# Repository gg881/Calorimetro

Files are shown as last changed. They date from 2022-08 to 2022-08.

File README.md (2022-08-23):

# Calorímetro

Neste github estão todos os arquivos do projeto, entre eles arquivos de construção mecânica, arquivo de software, firmware, executável e alguns ensaios.
Existem 3 vídeos explicando melhor sobre o projeto.

<br>

**Vídeo 1:**  Aborda sobre os detalhes da construção do projeto

Video 1 (https://www.youtube.com/watch?v=RRTPrstH1NE)

<br>

**Vídeo 2:**  Software, seu uso e procedimento de ensaio

Video 2 (https://www.youtube.com/watch?v=yg-kUi77DBA)

<br>

**Video3:** Procedimento de análise e resultados

Video 2 (https://www.youtube.com/watch?v=zke7yPpmnRY)

<br>
<br>

Contato:
gafaria@gmail.com ou gabriel.costa.faria@alumni.usp.br

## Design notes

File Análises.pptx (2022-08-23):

## Análise dos dados

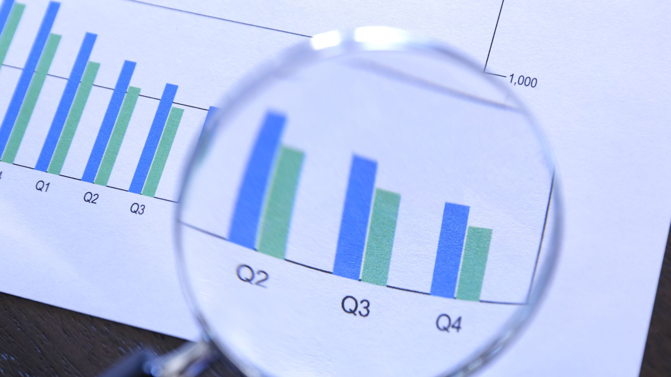
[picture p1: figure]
Lupa mostrando declínio de desempenho

## Tensão do ensaio

- Variando a tensão do ensaio, varia a potência máxima aplicada na amostra

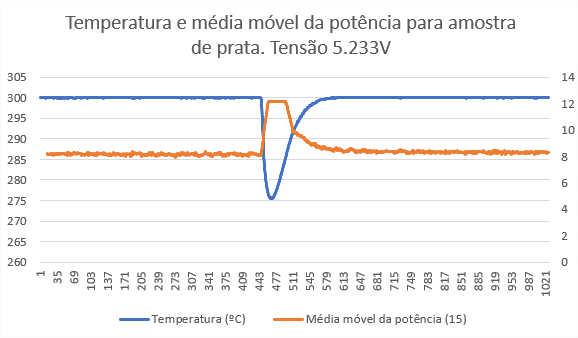
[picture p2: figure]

Pico de 12W, sem overshoot

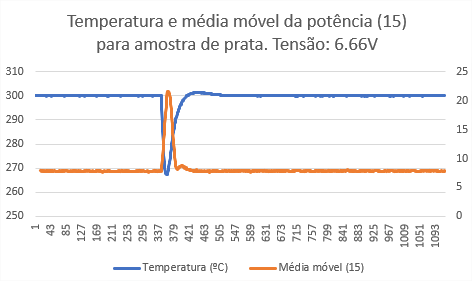
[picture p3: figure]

Pico de 21W. Teve overshoot!

## Como regular tensão

- Abrir a tampa frontal e ajustar no parafuso do trimpot rotacionando-o (o da esquerda). O trimpot da direita é a corrente limite.
- Pode deixar a saída manual em 1, verificando a máxima potência do ensaio.

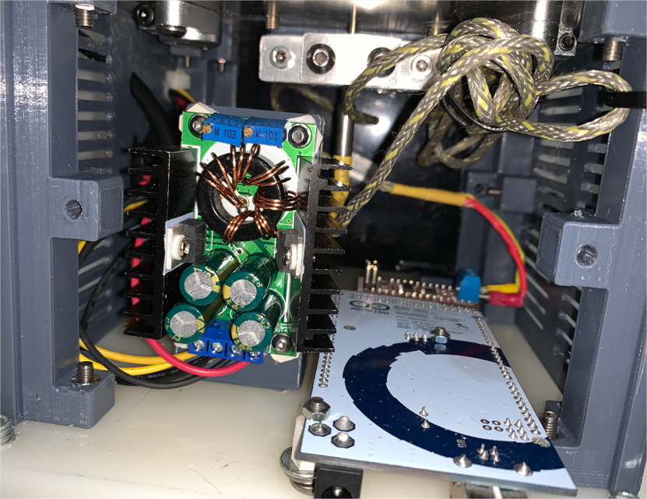
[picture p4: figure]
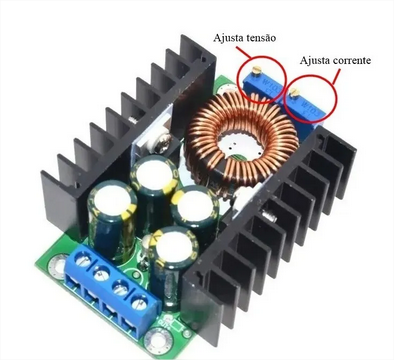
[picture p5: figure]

## Fim do ensaio quando não tem overshoot

- Considerado o momento que a temperatura atinge o patamar

## Fim do ensaio quando teve overshoot

- Considerado o momento que a temperatura retorna do overshoot (terminou o ciclo)

## Potências de estabilização com e sem a amostra

- São diferentes na maioria das vezes!
- Potência antes: 8.112W
- Potência depois: 8.270W
Mesmo pequena, afeta muito o resultado final
Em alguns casos chega a 0.3W a diferença

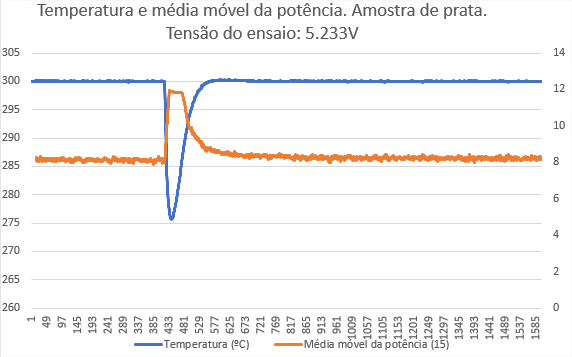
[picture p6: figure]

## Potências de estabilização com e sem a amostra

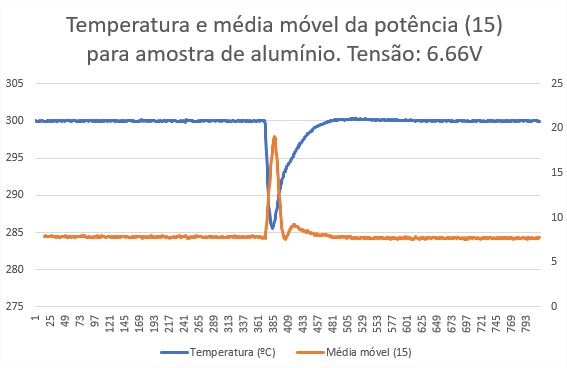
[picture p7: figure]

- Potência antes: 7,844W
- Potência depois: 7,707W

## Procedimento do ensaio

- Definir a temperatura do ensaio e valor do PID
- Esperar o aquecimento e estabilização da temperatura
- Começar a captura dos dados e capturar dados antes da amostra
- Colocar amostra e capturar dados depois da temperatura retornar
- Finalizar a captura de dados
- Análise dos dados no Excel

## Procedimento do cálculo dos valores (Excel)

- Nos ensaios foi considerada a 50% da média antes e 50% depois.
- O tempo inicial foi considerado o tempo que começa a cair a temperatura.
- O tempo final foi considerado de acordo com a existência de overshoot. Com ele: quando retorna do overshoot pela primeira vez. Sem ele: quando retorna para a temperatura definida pela primeira vez após o ensaio.
- É calculado o tempo do ensaio e a potência média durante o ensaio e potência média antes e depois.
- Fórmula usada: = (potência média do ensaio - (0,5*potência média antes do ensaio + 0,5* potência média depois do ensaio) ) ) * tempo do ensaio

## planilha

## Zinco

- P: 5.68 I: 104.06 D: 26.00 Tensão:6.631 V
- Temperatura ambiente: 21.0ºC
- Massa: 3,246 g

## Zinco amostra 1

Teve overshoot. Energia absorvida: 376,5 J

## Zinco amostra 2

Teve overshoot. Energia absorvida: 377,6 J

## Zinco amostra 3

Teve overshoot. Energia absorvida: 394,2 J

Média dos ensaios: 382,9 J

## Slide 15

Média dos ensaios: 382,9 J
Cálculo do valor esperado teórico:
Temperatura inicial média: 20,5ºC
No intervalo:

=1785,95 cal/mol = 7472,4 J/mol = 114,29 J/g * 3,246g = 370,99 J
Valor esperado: 371,0 J
Erro relativo: (382,9-371)/371 = 0,032 = 3.2% de erro

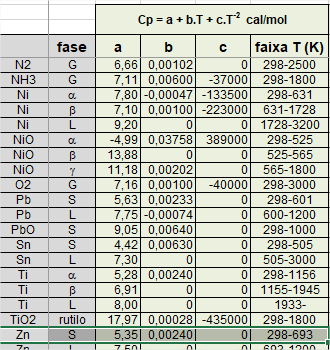
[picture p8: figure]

## Outra fonte de dados

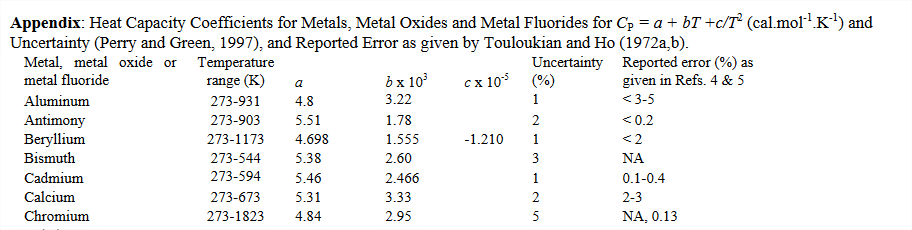
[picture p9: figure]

= 114,82 J/g = 372,7 J
Erro relativo: (382,9-372,7)/372,7 = 0,027 = 2,7% de erro

## E se a tensão for menor?

- Amostras com 5.236V
- P: 12.00 I: 119.90 D: 29.90

## Amostra 1b

Energia absorvida: 347,2 J

Ensaio ruim:
Não estava estabilizada a potência

## Amostra 2b

Energia absorvida: 364,5 J

## Amostra 2c

Ensaio ruim:
Não estava estabilizada a potência

Energia absorvida: 344,5 J

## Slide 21

- Média das amostras: 352,1 J
- Fonte 1: (352,1-371,0)/371,0 = -0,051 = – 5,1 % erro
- Fonte 2: (352,1-372,7)/372,7 =-0,055 = – 5,5% erro
- Ensaio ruim, patamar não estável

## E se a tensão for maior?

P: 3.00 I: 118.00 D: 29.50 Tensão:9.482 V Temperatura ambiente: 23.61ºC

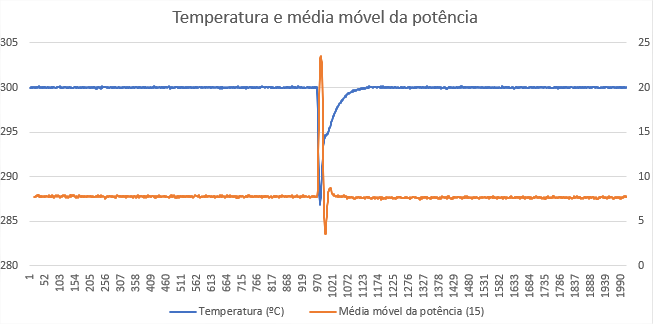
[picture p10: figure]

Amostra 1: 372,8 J

## E se a tensão for maior?

P: 3.00 I: 118.00 D: 29.50 Tensão:9.482 V Temperatura ambiente: 23.61ºC

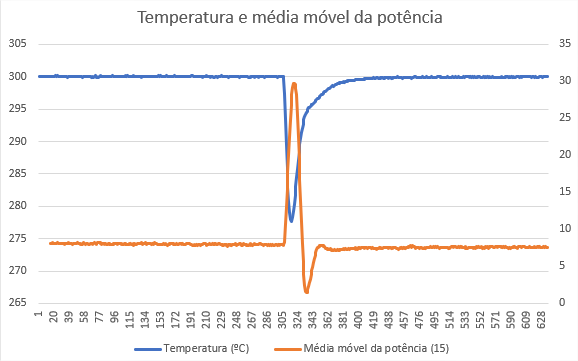
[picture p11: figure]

Amostra 2: 388,1 J

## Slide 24

- Média das amostras: 380,45 J
- Fonte 1: (380,45-371,0)/371,0 = 0,025 = 2,5 % erro
- Fonte 2: (380,4-372,7)/372,7 = 0,021 = 2,1% erro

## Amostra de prata

P: 5.68 I: 104.06 D: 26.00
Tensão:6.636 V
Temperatura ambiente: 21.73ºC
Massa: 8,852g

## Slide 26

Amostra 1: 666,7J
Amostra 2: 610,5 j
Amostra 3: 699,7 J
Média de 648,9 J

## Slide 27

1740,8 cal/mol * 4,184 J/cal / 107,868 g/mol = 67,52 J/g * 8,852g = 597,7 J

Erro relativo = (648,9-597,7)/597,7 = 0,085 = 8,5% de erro

## Amostra de prata – tensão menor

- P: 12.50 I: 100.00 D: 23.80
- Tensão:5.233 V

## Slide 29

- Amostra 1: 614,1 J
- Amostra 2: 552,2 J
- Amostra 3: 580,7 J
- Média: 582,3 J
- Erro relativo: (582,3-597,7)/597,7 = -0,0257 = -2,6% de erro

## Amostra de chumbo (chumbada de pesca)

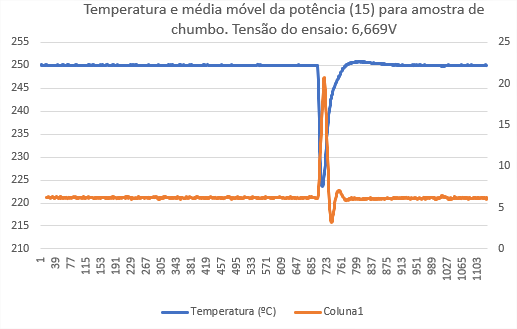
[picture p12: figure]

Amostra 1: Teve overshoot. Energia absorvida: 375,8 J

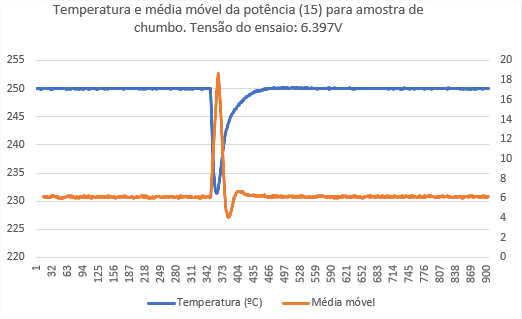
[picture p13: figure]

Amostra 2: Sem overshoot. Energia absorvida: 361,3 J

- Somente 2 ensaios (um em cada tensão)
- Média: 368,5 J

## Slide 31

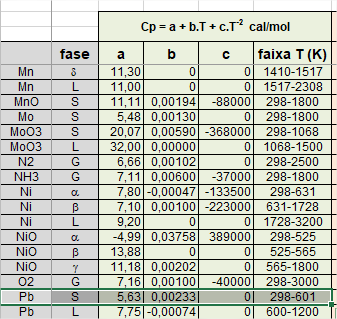
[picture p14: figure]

1488,28 cal/mol * 4,184 J/cal / 207,2 g/mol = 30,05 J/g
30,05 J/g * 12,448g = 374,1 J
Valor obtido experimentalmente: 368,5 J
Erro relativo: (368,5-374,1)/374,1 = -0,0149 = -1,5% de erro

## Amostra de Alumínio

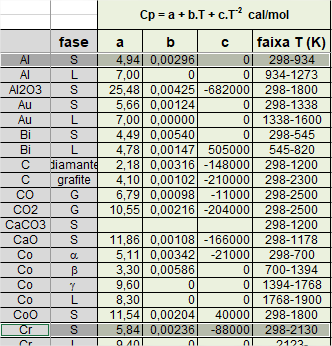
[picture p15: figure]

- Liga 5052 (~ 96,7% de Al)
- Considerado como somente alumínio
- Ensaio em 300ºC

1736,26cal/mol * 4,184 J/cal / 26,98 g/mol = 269,25 J/g

Para a amostra:
Valor esperado: 269,2 J/g*1,676g = 451,3

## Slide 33

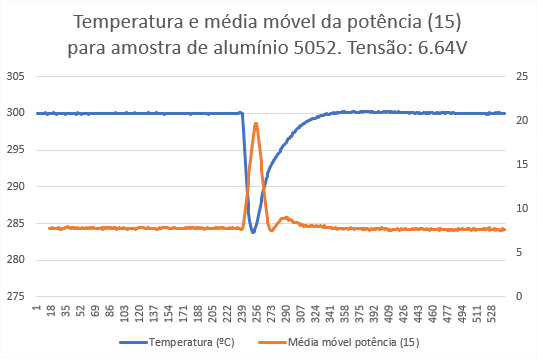
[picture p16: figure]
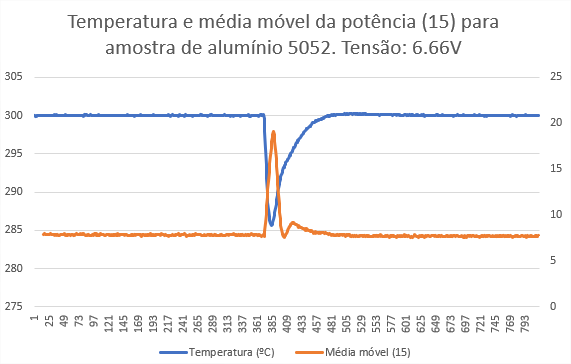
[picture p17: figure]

Teve overshoot.
Amostra 1: 437,3 J
Amostra 2: 419,5 J
Amostra 3: 445,3 J
Média de 434,0 J
Erro relativo: (434,0-451,3)/451,3 = -0,038 = -3,8% de erro

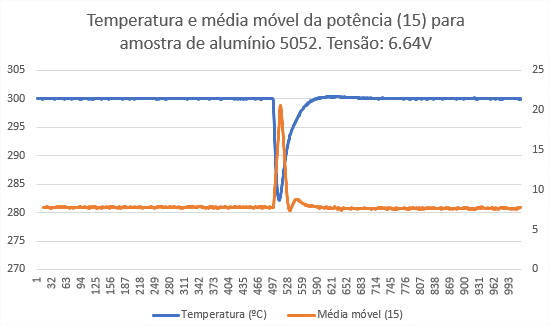
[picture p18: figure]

## Resumo

Amostra | Overshoot | Valor esperado | Valor obtido | Erro relativo
Zinco (6,631V) | sim | 371,0 J | 382,9 J | +3,2 %
Zinco (9,482V) | sim | 371,0 J | 380,45 J | +2,5 %
Prata 99% (6,67V) | sim | 597,7 J | 648,9 J | +8,5 %
Prata 99% (5,23V) | não | 597,7 J | 582,3 J | -2,6 %
Chumbo (chumbada) | ambos | 374,1 J | 368,5 J | -1,5%
Alumínio 5052 | sim | 451,3 J | 434,0 J | -3,8 %

## Sugestão de melhoria

- Realizar mais testes com e sem overshoot e protocolo de medição
- Ensaios para determinar tensão correta do ensaio
- Implementar medida automática no software
- Verificar precisão do termopar
- Verificar precisão do sensor de corrente
- Altura correta do termopar? Gradiente de temperatura no calorímetro?
- Tamanho ideal de amostra?

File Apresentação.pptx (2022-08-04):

## Calorímetro

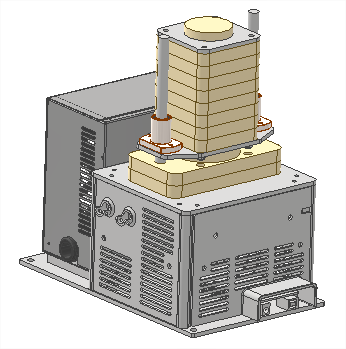
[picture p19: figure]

Documentação em:
www.github.com/gg881/Calorimetro

## Mede a quantidade de energia absorvida pela amostra até temperatura de teste

## Documentação em: www.github.com/gg881/Calorimetro

## Construção mecânica

- Modelado no Autodesk Inventor
- Construído com placas de fibra cerâmica, chapa de alumínio, nylon e partes impressas em PETG

## Eletrônica

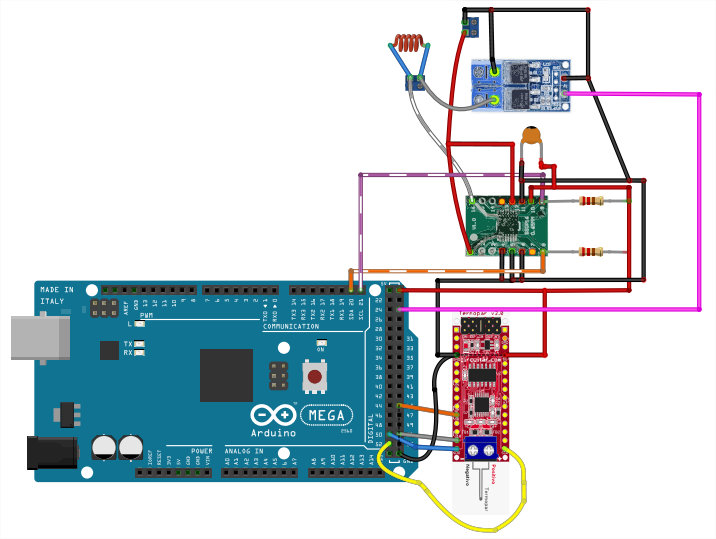
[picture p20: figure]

- Sensor de corrente e tensão (INA260)
- Sensor de temperatura (MAX31856)
- Arduino Mega 2560
- Mosfet para controle de potência
- Fonte 12v e regulador de tensão

## Medida da temperatura

- Módulo termopar da circuitar
- Baseado no CI MAX31856
- Linearização automática
- Suporta 8 tipos de termopares (K é o usado)
- Compensação junta fria
- Resolução de temperatura de 0.0078125°C (com termopar perfeito)

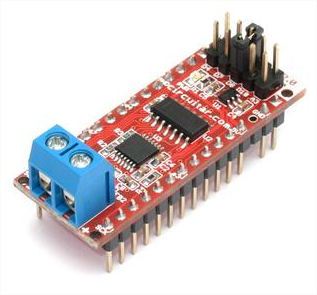
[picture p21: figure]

## Como é medida a corrente?

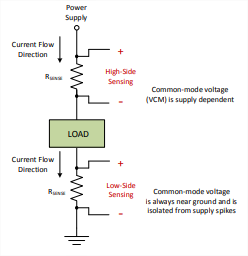
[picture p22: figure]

- Resistor shunt
- queda de tensão no resistor é proporcional à corrente
- Deve ser preciso, de baixo valor e termicamente estável

- https://www.ti.com/lit/an/sboa169b/sboa169b.pdf?ts=1653135314645

## Sensor de corrente – INA260

- Já vem com shunt interno (2mOhm) – 0,1%
- Resolução 1,25mA e 1,25mV
- -15A até 15A
- Até 16,488mS por leitura

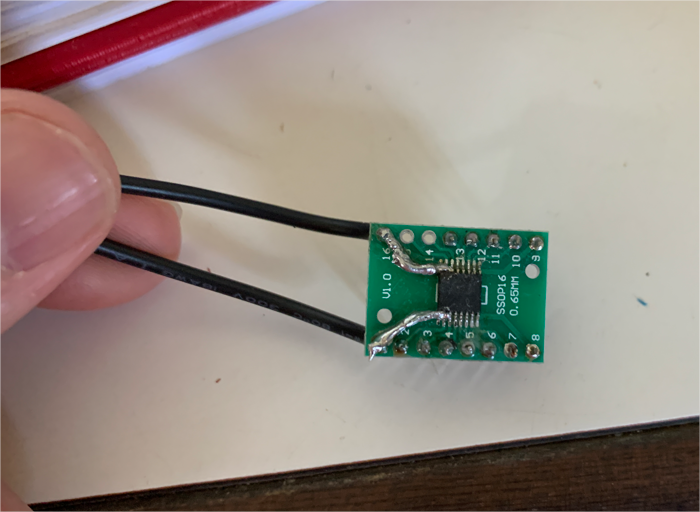
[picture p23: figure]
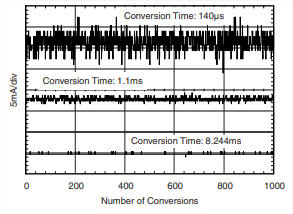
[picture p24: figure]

## Como é controlada a potência?

- Mosfet N
- Modulação PWM com período de 125 leituras do sensor (~2s)


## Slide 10


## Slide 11


## Firmware

- Lê os sensores
- Calcula a saída de carga a cada 125 leituras (algoritmo PID)
- Controla a saída
- Lê comandos do computador
- Formata e envia dados para o computador


## Algoritmo Proporcional Integrativo Derivativo (PID)

- Modula a potência de saída para que a temperatura seja constante


## PID

- Para cada sistema tem que ser calibrados os valores de P, I e D
- Não é trivial o ajuste sem um método.
- Centenas de métodos e variações
- O mais tradicional é o de Ziegler-Nichols

## Ziegler-Nichols


https://blog.opticontrols.com/archives/477

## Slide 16


## Ziegler-Nichols (frequência)


- No modo manual, colocar valores até começar a oscilar.

https://eng.libretexts.org/Bookshelves/Industrial_and_Systems_Engineering/Book%3A_Chemical_Process_Dynamics_and_Controls_(Woolf)/09%3A_Proportional-Integral-Derivati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

## Método de Astrom–Hagglund

- Método para calibração rápida
- Colocar em “bang-bang” e medir frequência e amplitude


Livro: Autotuning of PID Controllers Relay Feedback Approach - Cheng-Ching Yu - Springer


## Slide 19


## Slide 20


https://www.ni.com/pt-br/innovations/white-papers/06/pid-theory-explained.html

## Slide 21


https://www.pid-tuner.com/pid-control/

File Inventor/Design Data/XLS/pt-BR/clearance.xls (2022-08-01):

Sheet: Ansi Unified Screw Threads
I | Sort Order -1
Fastener Type | Size | Shaft Diameters |  |  | Head Dimensions
 |  | Close | Normal | Loose | Diameter | Depth/Angle | Head Type
Flat Head Machine Screw (82) | #0 | 0.0635 | 0.07 | 0.073 | 0.119 | 82 | 2
Flat Head Machine Screw (82) | #1 | 0.076 | 0.081 | 0.089 | 0.146 | 82 | 2
Flat Head Machine Screw (82) | #2 | 0.089 | 0.096 | 0.1065 | 0.172 | 82 | 2
Flat Head Machine Screw (82) | #3 | 0.104 | 0.11 | 0.12 | 0.199 | 82 | 2
Flat Head Machine Screw (82) | #4 | 0.116 | 0.1285 | 0.136 | 0.225 | 82 | 2
Flat Head Machine Screw (82) | #5 | 0.1285 | 0.136 | 0.154 | 0.252 | 82 | 2
Flat Head Machine Screw (82) | #6 | 0.144 | 0.1495 | 0.1695 | 0.279 | 82 | 2
Flat Head Machine Screw (82) | #8 | 0.1695 | 0.177 | 0.1935 | 0.332 | 82 | 2
Flat Head Machine Screw (82) | #10 | 0.196 | 0.201 | 0.221 | 0.385 | 82 | 2
Flat Head Machine Screw (82) | #12 | 0.221 | 0.228 | 0.246 | 0.438 | 82 | 2
Flat Head Machine Screw (82) | 1/4 | 0.257 | 0.266 | 0.2812 | 0.507 | 82 | 2
Flat Head Machine Screw (82) | 5/16 | 0.323 | 0.332 | 0.3437 | 0.635 | 82 | 2
Flat Head Machine Screw (82) | 3/8 | 0.386 | 0.397 | 0.4062 | 0.762 | 82 | 2
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

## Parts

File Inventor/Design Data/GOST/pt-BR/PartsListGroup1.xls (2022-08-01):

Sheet: Лист 1
Инв. № подл |  |  |  | Подп. и дата | Взам. инв. № | Инв. № дубл. |  |  | Подп. и дата
Формат | Зона | Поз. | Обозначение |  |  |  | Наименование |  |  |  |  |  | Кол. на исполнение
 |  |  |  |  |  |  |  |  |  |  |  | Лит.
 |  |  |  |  |  |  |  |  |  |  |  | Код
 |  |  |  |  |  |  |  | Изм. | Лист | № докум | Подпись |  | Дата
 |  |  |  |  |  |  |  | Разраб.
 |  |  |  |  |  |  |  | Пров.
 |  |  |  |  |  |  |  | Н.контр
 |  |  |  |  |  |  |  | Утв.
 |  |  |  |  |  |  |  |  |  |  |  |  |  | Копировал

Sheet: Лист 2
Инв. № подл |  |  |  | Подп. и дата | Взам. инв. № | Инв. № дубл. |  |  | Подп. и дата
Формат | Зона | Поз. | Обозначение |  |  |  | Наименование |  |  |  |  | Кол. на исполнение
 |  |  |  |  |  |  |  | Изм. | Лист | № докум. | Подп. | Дата
 |  |  |  |  |  |  |  |  |  |  |  |  | Копировал
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

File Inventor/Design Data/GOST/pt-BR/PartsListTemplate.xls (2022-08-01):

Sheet: Лист 1
 | Формат | Зона |  | Поз. |  | Обозначение |  |  |  | Наименование |  |  |  | Кол. | Приме-чание
Подп. и дата
Инв. № дубл.
Взам. инв. №
Подп. и дата
 | Изм. |  | Лист |  | № докум |  | Подпись | Дата
Инв. № подл | Разраб. |  |  |  |  |  |  |  |  |  | Литера |  | Лист |  |  | Листов
 | Пров.
 | Н.контр
 | Утв.
 |  |  |  |  |  |  |  |  | Копировал |  |  | Формат А4

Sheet: Лист 2
 | Формат | Зона |  | Поз. |  | Обозначение |  |  |  | Наименование |  | Кол. | Приме-чание
Подп. и дата
Инв. № дубл.
Взам. инв. №
Подп. и дата
Инв. № подл
 | Изм. |  | Лист |  | № докум. |  | Подп. |  | Дата
 |  |  |  |  |  |  |  | Копировал |  |  | Формат А4
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

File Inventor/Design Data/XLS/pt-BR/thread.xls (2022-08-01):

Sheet: Inch Tapping Threads
I Q X | Inch Tapping Threads |  | Sort Order - 5 |  | External |  |  |  |  |  |  | Internal
 |  |  |  |  |  | Major Dia |  | Pitch Dia |  | Minor Dia |  |  | Minor Dia |  | Pitch Dia |  | Major Dia |  | Tap Drill
Size | Size Suffix | Thread Designation | Custom Thread Designation | TPI | Class | Max | Min | Max | Min | Max | Min | Class | Min | Max | Min | Max | Min | Max | Basic
0.0600 |  | 0-48 | 0-48 | 48 | 2B | 0.0600 | 0.0540 | 0.0480 | 0.0435 | 0.0360 | 0.0330
0.0730 |  | 1-42 | 1-42 | 42 | 2B | 0.0750 | 0.0690 | 0.0620 | 0.0575 | 0.0490 | 0.0460
0.0860 |  | 2-32 | 2-32 | 32 | 2B | 0.0880 | 0.0820 | 0.0760 | 0.0710 | 0.0640 | 0.0600
0.0990 |  | 3-28 | 3-28 | 28 | 2B | 0.1010 | 0.0950 | 0.0880 | 0.0830 | 0.0750 | 0.0710
0.1120 |  | 4-24 | 4-24 | 24 | 2B | 0.1140 | 0.1080 | 0.1000 | 0.0950 | 0.0860 | 0.0820
0.1250 |  | 5-20 | 5-20 | 20 | 2B | 0.1300 | 0.1230 | 0.1120 | 0.1065 | 0.0940 | 0.0900
0.1380 |  | 6-20 | 6-20 | 20 | 2B | 0.1390 | 0.1320 | 0.1215 | 0.1155 | 0.1040 | 0.0990
0.1510 |  | 7-19 | 7-19 | 19 | 2B | 0.1540 | 0.1470 | 0.1345 | 0.1280 | 0.1150 | 0.1090
0.1640 |  | 8-18 | 8-18 | 18 | 2B | 0.1660 | 0.1590 | 0.1440 | 0.1375 | 0.1220 | 0.1160
0.1900 |  | 10-16 | 10-16 | 16 | 2B | 0.1890 | 0.1820 | 0.1650 | 0.1585 | 0.1410 | 0.1350
0.2160 |  | 12-14 | 12-14 | 14 | 2B | 0.2150 | 0.2080 | 0.1895 | 0.1825 | 0.1640 | 0.1570
0.2420 |  | 14-14 | 14-14 | 14 | 2B | 0.2410 | 0.2340 | 0.2130 | 0.2060 | 0.1850 | 0.1780
0.2500 |  | 1/4-14 | 1/4-14 | 14 | 2B | 0.2460 | 0.2370 | 0.2190 | 0.2110 | 0.1920 | 0.1850
0.3125 |  | 5/16-12 | 5/16-12 | 12 | 2B | 0.3150 | 0.3060 | 0.2795 | 0.2710 | 0.2440 | 0.2360
0.3750 |  | 3/8-12 | 3/8-12 | 12 | 2B | 0.3800 | 0.3710 | 0.3445 | 0.3350 | 0.3090 | 0.2990
0.4375 |  | 7/16-10 | 7/16-10 | 10 | 2B | 0.4400 | 0.4290 | 0.3995 | 0.3890 | 0.3590 | 0.3490
0.5000 |  | 1/2-10 | 1/2-10 | 10 | 2B | 0.5040 | 0.4930 | 0.4635 | 0.4530 | 0.4230 | 0.4130

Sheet: Metric Forming Screw Threads
M P X | Metric Forming Screw Threads |  | Sort Order - 6 |  | External |  |  |  |  |  |  | Internal
 |  |  |  |  |  | Major Dia |  | Pitch Dia |  | Minor Dia |  |  | Minor Dia |  | Pitch Dia |  | Major Dia |  | Tap Drill
Size | Size Suffix | Thread Designation | Custom Thread Designation | Pitch | Class | Max | Min | Max | Min | Max | Min | Class | Min | Max | Min | Max | Min | Max | Basic
1.5 |  | 1.5x0.5 | 1.5x0.5 | 0.5 | 6g | 1.520 | 1.380 | 1.215 | 1.110 | 0.910 | 0.840
1.5 |  | ST1.5x0.5 | ST1.5x0.5 | 0.5 | 6g | 1.520 | 1.380 | 1.215 | 1.110 | 0.910 | 0.840
1.9 |  | 1.9x0.6 | 1.9x0.6 | 0.6 | 6g | 1.900 | 1.760 | 1.570 | 1.465 | 1.240 | 1.170
1.9 |  | ST1.9x0.6 | ST1.9x0.6 | 0.6 | 6g | 1.900 | 1.760 | 1.570 | 1.465 | 1.240 | 1.170
2.2 |  | 2.2x0.8 | 2.2x0.8 | 0.8 | 6g | 2.240 | 2.100 | 1.935 | 1.810 | 1.630 | 1.520
2.2 |  | ST2.2x0.8 | ST2.2x0.8 | 0.8 | 6g | 2.240 | 2.100 | 1.935 | 1.810 | 1.630 | 1.520
2.6 |  | 2.6x0.9 | 2.6x0.9 | 0.9 | 6g | 2.570 | 2.430 | 2.235 | 2.115 | 1.900 | 1.800
2.6 |  | ST2.6x0.9 | ST2.6x0.9 | 0.9 | 6g | 2.570 | 2.430 | 2.235 | 2.115 | 1.900 | 1.800
2.9 |  | 2.9x1 | 2.9x1 | 1 | 6g | 2.900 | 2.760 | 2.540 | 2.420 | 2.180 | 2.080
2.9 |  | 2.9x1.1 | 2.9x1.1 | 1.1 | 6g | 2.900 | 2.760 | 2.540 | 2.420 | 2.180 | 2.080
2.9 |  | ST2.9x1.1 | ST2.9x1.1 | 1.1 | 6g | 2.900 | 2.760 | 2.540 | 2.420 | 2.180 | 2.080
2.9 |  | 2.9x1.3 | 2.9x1.3 | 1.3 | 6g | 2.900 | 2.720 | 2.540 | 2.355 | 1.890 | 1.700
2.9 |  | 2.9x1.4 | 2.9x1.4 | 1.4 | 6g | 2.900 | 2.720 | 2.340 | 2.175 | 1.780 | 1.630
3.3 |  | 3.3x1.3 | 3.3x1.3 | 1.3 | 6g | 3.300 | 3.120 | 2.795 | 2.665 | 2.290 | 2.210
3.3 |  | ST3.3x1.3 | ST3.3x1.3 | 1.3 | 6g | 3.300 | 3.120 | 2.795 | 2.665 | 2.290 | 2.210
3.5 |  | 3.5x1.3 | 3.5x1.3 | 1.3 | 6g | 3.530 | 3.350 | 3.085 | 2.930 | 2.640 | 2.510
3.5 |  | ST3.5x1.3 | ST3.5x1.3 | 1.3 | 6g | 3.530 | 3.350 | 3.085 | 2.930 | 2.640 | 2.510
3.5 |  | 3.5x1.6 | 3.5x1.6 | 1.6 | 6g | 3.530 | 3.350 | 2.920 | 2.755 | 2.310 | 2.160
3.5 |  | 3.5x3.2 | 3.5x3.2 | 3.2 | 6g | 3.530 | 3.310 | 2.800 | 2.600 | 2.070 | 1.890
3.9 |  | 3.9x1.3 | 3.9x1.3 | 1.3 | 6g | 3.910 | 3.730 | 3.415 | 3.250 | 2.920 | 2.770
3.9 |  | ST3.9x1.3 | ST3.9x1.3 | 1.3 | 6g | 3.910 | 3.730 | 3.415 | 3.250 | 2.920 | 2.770
3.9 |  | 3.9x1.6 | 3.9x1.6 | 1.6 | 6g | 3.910 | 3.730 | 3.300 | 3.135 | 2.690 | 2.540
3.9 |  | 3.9x3.2 | 3.9x3.2 | 3.2 | 6g | 3.910 | 3.690 | 3.180 | 2.980 | 2.450 | 2.270
4.2 |  | 4.2x1.4 | 4.2x1.4 | 1.4 | 6g | 4.220 | 4.040 | 3.660 | 3.495 | 3.100 | 2.950
4.2 |  | ST4.2x1.4 | ST4.2x1.4 | 1.4 | 6g | 4.220 | 4.040 | 3.660 | 3.495 | 3.100 | 2.950
4.2 |  | 4.2x1.6 | 4.2x1.6 | 1.6 | 6g | 4.220 | 4.040 | 3.610 | 3.445 | 3.000 | 2.850
4.2 |  | 4.2x3.2 | 4.2x3.2 | 3.2 | 6g | 4.220 | 4.000 | 3.380 | 3.180 | 2.540 | 2.360
4.8 |  | 4.8x1.6 | 4.8x1.6 | 1.6 | 6g | 4.800 | 4.620 | 4.190 | 4.025 | 3.580 | 3.430
4.8 |  | ST4.8x1.6 | ST4.8x1.6 | 1.6 | 6g | 4.800 | 4.620 | 4.190 | 4.025 | 3.580 | 3.430
4.8 |  | 4.8x1.8 | 4.8x1.8 | 1.8 | 6g | 4.800 | 4.620 | 4.065 | 3.885 | 3.330 | 3.150
4.8 |  | 4.8x3.2 | 4.8x3.2 | 3.2 | 6g | 4.800 | 4.580 | 3.960 | 3.760 | 3.120 | 2.940
5.5 |  | 5.5x1.8 | 5.5x1.8 | 1.8 | 6g | 5.460 | 5.280 | 4.815 | 4.635 | 4.170 | 3.990
5.5 |  | ST5.5x1.8 | ST5.5x1.8 | 1.8 | 6g | 5.460 | 5.280 | 4.815 | 4.635 | 4.170 | 3.990
6.3 |  | 6.3x1.8 | 6.3x1.8 | 1.8 | 6g | 6.250 | 6.030 | 5.565 | 5.365 | 4.880 | 4.700
6.3 |  | ST6.3x1.8 | ST6.3x1.8 | 1.8 | 6g | 6.250 | 6.030 | 5.565 | 5.365 | 4.880 | 4.700
8.0 |  | 8x2.1 | 8x2.1 | 2.1 | 6g | 8.000 | 7.780 | 7.100 | 6.885 | 6.200 | 5.990
8.0 |  | ST8x2.1 | ST8x2.1 | 2.1 | 6g | 8.000 | 7.780 | 7.100 | 6.885 | 6.200 | 5.990
9.5 |  | 9.5x2.1 | 9.5x2.1 | 2.1 | 6g | 9.650 | 9.430 | 8.750 | 8.510 | 7.850 | 7.590
9.5 |  | ST9.5x2.1 | ST9.5x2.1 | 2.1 | 6g | 9.650 | 9.430 | 8.750 | 8.510 | 7.850 | 7.590

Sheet: ISO Pipe Threads
M Q | ISO Pipe Threads |  | Sort Order - 9 |  | External |  |  |  |  |  |  | Internal
 |  |  |  |  |  | Major Dia |  | Pitch Dia |  | Minor Dia |  |  | Minor Dia |  | Pitch Dia |  | Major Dia |  | Tap Drill | Thread Depth | Thread Runouts
Size | Size Suffix | Thread Designation | Custom Thread Designation | TPI | Class | Max | Min | Max | Min | Max | Min | Class | Min | Max | Min | Max | Min | Max | Basic
7.723 |  | G7.723x0.907 | G 1/16 | 28 | A | 7.723 | 7.509 | 7.142 | 7.035 | 6.561 |  |  | 6.561 | 6.834 | 7.142 | 7.249 | 7.723 |  | 1.5875 | 15.446 | 4.5000
7.723 |  | G7.723x0.907 | G 1/16 | 28 | B | 7.723 | 7.509 | 7.142 | 6.928 | 6.561
9.728 |  | G9.728x0.907 | G 1/8 | 28 | A | 9.728 | 9.514 | 9.147 | 9.040 | 8.566 |  |  | 8.566 | 8.848 | 9.147 | 9.254 | 9.728 |  | 3.1750 | 19.456 | 4.5000
9.728 |  | G9.728x0.907 | G 1/8 | 28 | B | 9.728 | 9.514 | 9.147 | 8.933 | 8.566
13.157 |  | G13.157x1.337 | G 1/4 | 19 | A | 13.157 | 12.907 | 12.301 | 12.176 | 11.445 |  |  | 11.445 | 11.89 | 12.301 | 12.426 | 13.157 |  | 6.3500 | 26.314 | 6.5000
13.157 |  | G13.157x1.337 | G 1/4 | 19 | B | 13.157 | 12.907 | 12.301 | 12.051 | 11.445
16.662 |  | G16.662x1.337 | G 3/8 | 19 | A | 16.662 | 16.412 | 15.806 | 15.681 | 14.950 |  |  | 14.95 | 15.395 | 15.806 | 15.931 | 16.662 |  | 9.5250 | 33.324 | 6.5000
16.662 |  | G16.662x1.337 | G 3/8 | 19 | B | 16.662 | 16.412 | 15.806 | 15.556 | 14.950
20.955 |  | G20.955x1.814 | G 1/2 | 14 | A | 20.955 | 20.671 | 19.793 | 19.651 | 18.631 |  |  | 18.631 | 19.172 | 19.793 | 19.935 | 20.955 |  | 12.7000 | 41.910 | 8.5000
20.955 |  | G20.955x1.814 | G 1/2 | 14 | B | 20.955 | 20.671 | 19.793 | 19.509 | 18.631
22.911 |  | G22.911x1.814 | G 5/8 | 14 | A | 22.911 | 22.627 | 21.749 | 21.607 | 20.587 |  |  | 20.587 | 21.128 | 21.749 | 21.891 | 22.911 |  |  | 45.822 | 8.5000
22.911 |  | G22.911x1.814 | G 5/8 | 14 | B | 22.911 | 22.627 | 21.749 | 21.465 | 20.587
26.441 |  | G26.441x1.814 | G 3/4 | 14 | A | 26.441 | 26.157 | 25.279 | 25.137 | 24.117 |  |  | 24.117 | 24.658 | 25.279 | 25.421 | 26.441 |  | 15.8750 | 52.882 | 8.5000
26.441 |  | G26.441x1.814 | G 3/4 | 14 | B | 26.441 | 26.157 | 25.279 | 24.995 | 24.117
30.201 |  | G30.201x1.814 | G 7/8 | 14 | A | 30.201 | 29.917 | 29.039 | 28.897 | 27.877 |  |  | 27.877 | 28.418 | 29.039 | 29.181 | 30.201 |  | 22.2250 | 60.402 | 8.5000
30.201 |  | G30.201x1.814 | G 7/8 | 14 | B | 30.201 | 29.917 | 29.039 | 28.755 | 27.877
33.249 |  | G33.249x2.309 | G 1 | 11 | A | 33.249 | 32.889 | 31.770 | 31.590 | 30.291 |  |  | 30.291 | 30.931 | 31.77 | 31.95 | 33.249 |  | 25.4000 | 66.498 | 10.0000
33.249 |  | G33.249x2.309 | G 1 | 11 | B | 33.249 | 32.889 | 31.770 | 31.410 | 30.291
37.897 |  | G37.897x2.309 | G 1 1/8 | 11 | A | 37.897 | 37.537 | 36.418 | 36.238 | 34.939 |  |  | 34.939 | 35.579 | 36.418 | 36.598 | 37.897 |  | 28.5750 | 75.794 | 10.0000
37.897 |  | G37.897x2.309 | G 1 1/8 | 11 | B | 37.897 | 37.537 | 36.418 | 36.058 | 34.939
41.910 |  | G41.91x2.309 | G 1 1/4 | 11 | A | 41.910 | 41.550 | 40.431 | 40.251 | 38.952 |  |  | 38.952 | 39.592 | 40.431 | 40.611 | 41.910 |  | 31.7500 | 83.820 | 10.0000
41.910 |  | G41.91x2.309 | G 1 1/4 | 11 | B | 41.910 | 41.550 | 40.431 | 40.071 | 38.952
47.803 |  | G47.803x2.309 | G 1 1/2 | 11 | A | 47.803 | 47.443 | 46.324 | 46.144 | 44.845 |  |  | 44.845 | 45.485 | 46.324 | 46.504 | 47.803 |  | 38.1000 | 95.606 | 10.0000
47.803 |  | G47.803x2.309 | G 1 1/2 | 11 | B | 47.803 | 47.443 | 46.324 | 45.964 | 44.845
53.746 |  | G53.746x2.309 | G 1 3/4 | 11 | A | 53.746 | 53.386 | 52.267 | 52.087 | 50.788 |  |  | 50.788 | 51.428 | 52.267 | 52.447 | 53.746 |  | 44.4500 | 107.492 | 10.0000
53.746 |  | G53.746x2.309 | G 1 3/4 | 11 | B | 53.746 | 53.386 | 52.267 | 51.907 | 50.788
59.614 |  | G59.614x2.309 | G 2 | 11 | A | 59.614 | 59.254 | 58.135 | 57.955 | 56.656 |  |  | 56.656 | 57.296 | 58.135 | 58.315 | 59.614 |  | 50.8000 | 119.228 | 10.0000
59.614 |  | G59.614x2.309 | G 2 | 11 | B | 59.614 | 59.254 | 58.135 | 57.775 | 56.656
65.710 |  | G65.71x2.309 | G 2 1/4 | 11 | A | 65.710 | 65.276 | 64.231 | 64.014 | 62.752 |  |  | 62.752 | 63.392 | 64.231 | 64.448 | 65.710 |  | 57.1500 | 131.420 | 10.0000
65.710 |  | G65.71x2.309 | G 2 1/4 | 11 | B | 65.710 | 65.276 | 64.231 | 63.797 | 62.752
75.184 |  | G75.184x2.309 | G 2 1/2 | 11 | A | 75.184 | 74.750 | 73.705 | 73.488 | 72.226 |  |  | 72.226 | 72.866 | 73.705 | 73.922 | 75.184 |  |  | 150.368 | 10.0000
75.184 |  | G75.184x2.309 | G 2 1/2 | 11 | B | 75.184 | 74.750 | 73.705 | 73.271 | 72.226
81.534 |  | G81.534x2.309 | G 2 3/4 | 11 | A | 81.534 | 81.100 | 80.055 | 79.838 | 78.576 |  |  | 78.576 | 79.216 | 80.055 | 80.272 | 81.534 |  | 69.8500 | 163.068 | 10.0000
81.534 |  | G81.534x2.309 | G 2 3/4 | 11 | B | 81.534 | 81.100 | 80.055 | 79.621 | 78.576
87.884 |  | G87.884x2.309 | G 3 | 11 | A | 87.884 | 87.450 | 86.405 | 86.188 | 84.926 |  |  | 84.926 | 85.566 | 86.405 | 86.622 | 87.884 |  | 76.2000 | 175.768 | 10.0000
87.884 |  | G87.884x2.309 | G 3 | 11 | B | 87.884 | 87.450 | 86.405 | 85.971 | 84.926
100.330 |  | G100.33x2.309 | G 3 1/2 | 11 | A | 100.330 | 99.896 | 98.851 | 98.634 | 97.372 |  |  | 97.372 | 98.012 | 98.851 | 99.068 | 100.330 |  | 88.9000 | 200.660 | 10.0000
100.330 |  | G100.33x2.309 | G 3 1/2 | 11 | B | 100.330 | 99.896 | 98.851 | 98.417 | 97.372
113.030 |  | G113.03x2.309 | G 4 | 11 | A | 113.030 | 112.596 | 111.551 | 111.334 | 110.072 |  |  | 110.072 | 110.712 | 111.551 | 111.768 | 113.030 |  | 101.6000 | 226.060 | 10.0000
113.030 |  | G113.03x2.309 | G 4 | 11 | B | 113.030 | 112.596 | 111.551 | 111.117 | 110.072
125.730 |  | G125.73x2.309 | G 4 1/2 | 11 | A | 125.730 | 125.296 | 124.251 | 124.034 | 122.772 |  |  | 122.772 | 123.412 | 124.251 | 124.468 | 125.730 |  | 114.3000 | 251.460 | 10.0000
125.730 |  | G125.73x2.309 | G 4 1/2 | 11 | B | 125.730 | 125.296 | 124.251 | 123.817 | 122.772
138.430 |  | G138.43x2.309 | G 5 | 11 | A | 138.430 | 137.996 | 136.951 | 136.734 | 135.472 |  |  | 135.472 | 136.112 | 136.951 | 137.168 | 138.430 |  | 127.0000 | 276.860 | 10.0000
138.430 |  | G138.43x2.309 | G 5 | 11 | B | 138.430 | 137.996 | 136.951 | 136.517 | 135.472
151.130 |  | G151.13x2.309 | G 5 1/2 | 11 | A | 151.130 | 150.696 | 149.651 | 149.434 | 148.172 |  |  | 148.172 | 148.812 | 149.651 | 149.868 | 151.130 |  | 139.7000 | 302.260 | 10.0000
151.130 |  | G151.13x2.309 | G 5 1/2 | 11 | B | 151.130 | 150.696 | 149.651 | 149.217 | 148.172
163.830 |  | G163.83x2.309 | G 6 | 11 | A | 163.830 | 163.396 | 162.351 | 162.134 | 160.872 |  |  | 160.872 | 161.512 | 162.351 | 162.568 | 163.830 |  | 152.4000 | 327.660 | 10.0000
163.830 |  | G163.83x2.309 | G 6 | 11 | B | 163.830 | 163.396 | 162.351 | 161.917 | 160.872

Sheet: JIS Pipe Threads
M Q | JIS Pipe Threads |  | Sort Order -12 |  | External |  |  |  |  |  |  | Internal
 |  |  |  |  |  | Major Dia |  | Pitch Dia |  | Minor Dia |  |  | Minor Dia |  | Pitch Dia |  | Major Dia |  | Tap Drill | Thread Depth | Thread Runouts
Size | Size Suffix | Thread Designation | Custom Thread Designation | TPI | Class | Max | Min | Max | Min | Max | Min | Class | Min | Max | Min | Max | Min | Max | Basic |  | Basic
7.723 |  | G7.723x0.907 | G 1/16 | 28 | A | 7.723 | 7.509 | 7.142 | 7.035 | 6.561 |  |  | 6.561 | 6.834 | 7.142 | 7.249 | 7.723 |  | 1.5875 | 15.446 | 4.5000
7.723 |  | G7.723x0.907 | G 1/16 | 28 | B | 7.723 | 7.509 | 7.142 | 6.928 | 6.561
9.728 |  | G9.728x0.907 | G 1/8 | 28 | A | 9.728 | 9.514 | 9.147 | 9.040 | 8.566 |  |  | 8.566 | 8.848 | 9.147 | 9.254 | 9.728 |  | 3.1750 | 19.456 | 4.5000
9.728 |  | G9.728x0.907 | G 1/8 | 28 | B | 9.728 | 9.514 | 9.147 | 8.933 | 8.566
13.157 |  | G13.157x1.337 | G 1/4 | 19 | A | 13.157 | 12.907 | 12.301 | 12.176 | 11.445 |  |  | 11.445 | 11.89 | 12.301 | 12.426 | 13.157 |  | 6.3500 | 26.314 | 6.5000
13.157 |  | G13.157x1.337 | G 1/4 | 19 | B | 13.157 | 12.907 | 12.301 | 12.051 | 11.445
16.662 |  | G16.662x1.337 | G 3/8 | 19 | A | 16.662 | 16.412 | 15.806 | 15.681 | 14.950 |  |  | 14.95 | 15.395 | 15.806 | 15.931 | 16.662 |  | 9.5250 | 33.324 | 6.5000
16.662 |  | G16.662x1.337 | G 3/8 | 19 | B | 16.662 | 16.412 | 15.806 | 15.556 | 14.950
20.955 |  | G20.955x1.814 | G 1/2 | 14 | A | 20.955 | 20.671 | 19.793 | 19.651 | 18.631 |  |  | 18.631 | 19.172 | 19.793 | 19.935 | 20.955 |  | 12.7000 | 41.910 | 8.5000
20.955 |  | G20.955x1.814 | G 1/2 | 14 | B | 20.955 | 20.671 | 19.793 | 19.509 | 18.631
22.911 |  | G22.911x1.814 | G 5/8 | 14 | A | 22.911 | 22.627 | 21.749 | 21.607 | 20.587 |  |  | 20.587 | 21.128 | 21.749 | 21.891 | 22.911 |  |  | 45.822 | 8.5000
22.911 |  | G22.911x1.814 | G 5/8 | 14 | B | 22.911 | 22.627 | 21.749 | 21.465 | 20.587
26.441 |  | G26.441x1.814 | G 3/4 | 14 | A | 26.441 | 26.157 | 25.279 | 25.137 | 24.117 |  |  | 24.117 | 24.658 | 25.279 | 25.421 | 26.441 |  | 15.8750 | 52.882 | 8.5000
26.441 |  | G26.441x1.814 | G 3/4 | 14 | B | 26.441 | 26.157 | 25.279 | 24.995 | 24.117
30.201 |  | G30.201x1.814 | G 7/8 | 14 | A | 30.201 | 29.917 | 29.039 | 28.897 | 27.877 |  |  | 27.877 | 28.418 | 29.039 | 29.181 | 30.201 |  | 22.2250 | 60.402 | 8.8000
30.201 |  | G30.201x1.814 | G 7/8 | 14 | B | 30.201 | 29.917 | 29.039 | 28.755 | 27.877
33.249 |  | G33.249x2.309 | G 1 | 11 | A | 33.249 | 32.889 | 31.770 | 31.590 | 30.291 |  |  | 30.291 | 30.931 | 31.77 | 31.95 | 33.249 |  | 25.4000 | 66.498 | 10.0000
33.249 |  | G33.249x2.309 | G 1 | 11 | B | 33.249 | 32.889 | 31.770 | 31.410 | 30.291
37.897 |  | G37.897x2.309 | G 1 1/8 | 11 | A | 37.897 | 37.537 | 36.418 | 36.238 | 34.939 |  |  | 34.939 | 35.579 | 36.418 | 36.598 | 37.897 |  | 28.5750 | 75.794 | 10.0000
37.897 |  | G37.897x2.309 | G 1 1/8 | 11 | B | 37.897 | 37.537 | 36.418 | 36.058 | 34.939
41.910 |  | G41.91x2.309 | G 1 1/4 | 11 | A | 41.910 | 41.550 | 40.431 | 40.251 | 38.952 |  |  | 38.952 | 39.592 | 40.431 | 40.611 | 41.910 |  | 31.7500 | 83.820 | 10.0000
41.910 |  | G41.91x2.309 | G 1 1/4 | 11 | B | 41.910 | 41.550 | 40.431 | 40.071 | 38.952
47.803 |  | G47.803x2.309 | G 1 1/2 | 11 | A | 47.803 | 47.443 | 46.324 | 46.144 | 44.845 |  |  | 44.845 | 45.485 | 46.324 | 46.504 | 47.803 |  | 38.1000 | 95.606 | 10.0000
47.803 |  | G47.803x2.309 | G 1 1/2 | 11 | B | 47.803 | 47.443 | 46.324 | 45.964 | 44.845
53.746 |  | G53.746x2.309 | G 1 3/4 | 11 | A | 53.746 | 53.386 | 52.267 | 52.087 | 50.788 |  |  | 50.788 | 51.428 | 52.267 | 52.447 | 53.746 |  | 44.4500 | 107.492 | 10.0000
53.746 |  | G53.746x2.309 | G 1 3/4 | 11 | B | 53.746 | 53.386 | 52.267 | 51.907 | 50.788
59.614 |  | G59.614x2.309 | G 2 | 11 | A | 59.614 | 59.254 | 58.135 | 57.955 | 56.656 |  |  | 56.656 | 57.296 | 58.135 | 58.315 | 59.614 |  | 50.8000 | 119.228 | 10.0000
59.614 |  | G59.614x2.309 | G 2 | 11 | B | 59.614 | 59.254 | 58.135 | 57.775 | 56.656
65.710 |  | G65.71x2.309 | G 2 1/4 | 11 | A | 65.710 | 65.276 | 64.231 | 64.014 | 62.752 |  |  | 62.752 | 63.392 | 64.231 | 64.448 | 65.710 |  | 57.1500 | 131.420 | 10.0000
65.710 |  | G65.71x2.309 | G 2 1/4 | 11 | B | 65.710 | 65.276 | 64.231 | 63.797 | 62.752
75.184 |  | G75.184x2.309 | G 2 1/2 | 11 | A | 75.184 | 74.750 | 73.705 | 73.488 | 72.226 |  |  | 72.226 | 72.866 | 73.705 | 73.922 | 75.184 |  |  | 150.368 | 10.0000
75.184 |  | G75.184x2.309 | G 2 1/2 | 11 | B | 75.184 | 74.750 | 73.705 | 73.271 | 72.226
81.534 |  | G81.534x2.309 | G 2 3/4 | 11 | A | 81.534 | 81.100 | 80.055 | 79.838 | 78.576 |  |  | 78.576 | 79.216 | 80.055 | 80.272 | 81.534 |  | 69.8500 | 163.068 | 10.0000
81.534 |  | G81.534x2.309 | G 2 3/4 | 11 | B | 81.534 | 81.100 | 80.055 | 79.621 | 78.576
87.884 |  | G87.884x2.309 | G 3 | 11 | A | 87.884 | 87.450 | 86.405 | 86.188 | 84.926 |  |  | 84.926 | 85.566 | 86.405 | 86.622 | 87.884 |  | 76.2000 | 175.768 | 10.0000
87.884 |  | G87.884x2.309 | G 3 | 11 | B | 87.884 | 87.450 | 86.405 | 85.971 | 84.926
100.330 |  | G100.33x2.309 | G 3 1/2 | 11 | A | 100.330 | 99.896 | 98.851 | 98.634 | 97.372 |  |  | 97.372 | 98.012 | 98.851 | 99.068 | 100.330 |  | 88.9000 | 200.660 | 10.0000
100.330 |  | G100.33x2.309 | G 3 1/2 | 11 | B | 100.330 | 99.896 | 98.851 | 98.417 | 97.372
113.030 |  | G113.03x2.309 | G 4 | 11 | A | 113.030 | 112.596 | 111.551 | 111.334 | 110.072 |  |  | 110.072 | 110.712 | 111.551 | 111.768 | 113.030 |  | 101.6000 | 226.060 | 10.0000
113.030 |  | G113.03x2.309 | G 4 | 11 | B | 113.030 | 112.596 | 111.551 | 111.117 | 110.072
125.730 |  | G125.73x2.309 | G 4 1/2 | 11 | A | 125.730 | 125.296 | 124.251 | 124.034 | 122.772 |  |  | 122.772 | 123.412 | 124.251 | 124.468 | 125.730 |  | 114.3000 | 251.460 | 10.0000
125.730 |  | G125.73x2.309 | G 4 1/2 | 11 | B | 125.730 | 125.296 | 124.251 | 123.817 | 122.772
138.430 |  | G138.43x2.309 | G 5 | 11 | A | 138.430 | 137.996 | 136.951 | 136.734 | 135.472 |  |  | 135.472 | 136.112 | 136.951 | 137.168 | 138.430 |  | 127.0000 | 276.860 | 10.0000
138.430 |  | G138.43x2.309 | G 5 | 11 | B | 138.430 | 137.996 | 136.951 | 136.517 | 135.472
151.130 |  | G151.13x2.309 | G 5 1/2 | 11 | A | 151.130 | 150.696 | 149.651 | 149.434 | 148.172 |  |  | 148.172 | 148.812 | 149.651 | 149.868 | 151.130 |  | 139.7000 | 302.260 | 10.0000
151.130 |  | G151.13x2.309 | G 5 1/2 | 11 | B | 151.130 | 150.696 | 149.651 | 149.217 | 148.172
163.830 |  | G163.83x2.309 | G 6 | 11 | A | 163.830 | 163.396 | 162.351 | 162.134 | 160.872 |  |  | 160.872 | 161.512 | 162.351 | 162.568 | 163.830 |  | 152.4000 | 327.660 | 10.0000
163.830 |  | G163.83x2.309 | G 6 | 11 | B | 163.830 | 163.396 | 162.351 | 161.917 | 160.872

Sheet: DIN Pipe Threads
M Q | DIN Pipe Threads |  | Sort Order - 18 |  | External |  |  |  |  |  |  | Internal
 |  |  |  |  |  | Major Dia |  | Pitch Dia |  | Minor Dia |  |  | Minor Dia |  | Pitch Dia |  | Major Dia |  | Tap Drill | Thread Depth | Thread Runouts
Size | Size Suffix | Thread Designation | Custom Thread Designation | TPI | Class | Max | Min | Max | Min | Max | Min | Class | Min | Max | Min | Max | Min | Max | Basic
7.723 |  | G7.723x0.907 | G 1/16 | 28 | A | 7.723 | 7.509 | 7.142 | 7.035 | 6.561 |  |  | 6.561 | 6.834 | 7.142 | 7.249 | 7.723 |  | 1.5875 | 15.446 | 4.5000
7.723 |  | G7.723x0.907 | G 1/16 | 28 | B | 7.723 | 7.509 | 7.142 | 6.928 | 6.561
9.728 |  | G9.728x0.907 | G 1/8 | 28 | A | 9.728 | 9.514 | 9.147 | 9.040 | 8.566 |  |  | 8.566 | 8.848 | 9.147 | 9.254 | 9.728 |  | 3.1750 | 19.456 | 4.5000
9.728 |  | G9.728x0.907 | G 1/8 | 28 | B | 9.728 | 9.514 | 9.147 | 8.933 | 8.566
13.157 |  | G13.157x1.337 | G 1/4 | 19 | A | 13.157 | 12.907 | 12.301 | 12.176 | 11.445 |  |  | 11.445 | 11.89 | 12.301 | 12.426 | 13.157 |  | 6.3500 | 26.314 | 6.5000
13.157 |  | G13.157x1.337 | G 1/4 | 19 | B | 13.157 | 12.907 | 12.301 | 12.051 | 11.445
16.662 |  | G16.662x1.337 | G 3/8 | 19 | A | 16.662 | 16.412 | 15.806 | 15.681 | 14.950 |  |  | 14.95 | 15.395 | 15.806 | 15.931 | 16.662 |  | 9.5250 | 33.324 | 6.5000
16.662 |  | G16.662x1.337 | G 3/8 | 19 | B | 16.662 | 16.412 | 15.806 | 15.556 | 14.950
20.955 |  | G20.955x1.814 | G 1/2 | 14 | A | 20.955 | 20.671 | 19.793 | 19.651 | 18.631 |  |  | 18.631 | 19.172 | 19.793 | 19.935 | 20.955 |  | 12.7000 | 41.910 | 8.5000
20.955 |  | G20.955x1.814 | G 1/2 | 14 | B | 20.955 | 20.671 | 19.793 | 19.509 | 18.631
22.911 |  | G22.911x1.814 | G 5/8 | 14 | A | 22.911 | 22.627 | 21.749 | 21.607 | 20.587 |  |  | 20.587 | 21.128 | 21.749 | 21.891 | 22.911 |  |  | 45.822 | 8.5000
22.911 |  | G22.911x1.814 | G 5/8 | 14 | B | 22.911 | 22.627 | 21.749 | 21.465 | 20.587
26.441 |  | G26.441x1.814 | G 3/4 | 14 | A | 26.441 | 26.157 | 25.279 | 25.137 | 24.117 |  |  | 24.117 | 24.658 | 25.279 | 25.421 | 26.441 |  | 15.8750 | 52.882 | 8.5000
26.441 |  | G26.441x1.814 | G 3/4 | 14 | B | 26.441 | 26.157 | 25.279 | 24.995 | 24.117
30.201 |  | G30.201x1.814 | G 7/8 | 14 | A | 30.201 | 29.917 | 29.039 | 28.897 | 27.877 |  |  | 27.877 | 28.418 | 29.039 | 29.181 | 30.201 |  | 22.2250 | 60.402 | 8.5000
30.201 |  | G30.201x1.814 | G 7/8 | 14 | B | 30.201 | 29.917 | 29.039 | 28.755 | 27.877
33.249 |  | G33.249x2.309 | G 1 | 11 | A | 33.249 | 32.889 | 31.770 | 31.590 | 30.291 |  |  | 30.291 | 30.931 | 31.77 | 31.95 | 33.249 |  | 25.4000 | 66.498 | 10.5000
33.249 |  | G33.249x2.309 | G 1 | 11 | B | 33.249 | 32.889 | 31.770 | 31.410 | 30.291
37.897 |  | G37.897x2.309 | G 1 1/8 | 11 | A | 37.897 | 37.537 | 36.418 | 36.238 | 34.939 |  |  | 34.939 | 35.579 | 36.418 | 36.598 | 37.897 |  | 28.5750 | 75.794 | 10.5000
37.897 |  | G37.897x2.309 | G 1 1/8 | 11 | B | 37.897 | 37.537 | 36.418 | 36.058 | 34.939
41.910 |  | G41.91x2.309 | G 1 1/4 | 11 | A | 41.910 | 41.550 | 40.431 | 40.251 | 38.952 |  |  | 38.952 | 39.592 | 40.431 | 40.611 | 41.910 |  | 31.7500 | 83.820 | 10.5000
41.910 |  | G41.91x2.309 | G 1 1/4 | 11 | B | 41.910 | 41.550 | 40.431 | 40.071 | 38.952
47.803 |  | G47.803x2.309 | G 1 1/2 | 11 | A | 47.803 | 47.443 | 46.324 | 46.144 | 44.845 |  |  | 44.845 | 45.485 | 46.324 | 46.504 | 47.803 |  | 38.1000 | 95.606 | 10.5000
47.803 |  | G47.803x2.309 | G 1 1/2 | 11 | B | 47.803 | 47.443 | 46.324 | 45.964 | 44.845
53.746 |  | G53.746x2.309 | G 1 3/4 | 11 | A | 53.746 | 53.386 | 52.267 | 52.087 | 50.788 |  |  | 50.788 | 51.428 | 52.267 | 52.447 | 53.746 |  | 44.4500 | 107.492 | 10.5000
53.746 |  | G53.746x2.309 | G 1 3/4 | 11 | B | 53.746 | 53.386 | 52.267 | 51.907 | 50.788
59.614 |  | G59.614x2.309 | G 2 | 11 | A | 59.614 | 59.254 | 58.135 | 57.955 | 56.656 |  |  | 56.656 | 57.296 | 58.135 | 58.315 | 59.614 |  | 50.8000 | 119.228 | 10.5000
59.614 |  | G59.614x2.309 | G 2 | 11 | B | 59.614 | 59.254 | 58.135 | 57.775 | 56.656
65.710 |  | G65.71x2.309 | G 2 1/4 | 11 | A | 65.710 | 65.276 | 64.231 | 64.014 | 62.752 |  |  | 62.752 | 63.392 | 64.231 | 64.448 | 65.710 |  | 57.1500 | 131.420 | 10.5000
65.710 |  | G65.71x2.309 | G 2 1/4 | 11 | B | 65.710 | 65.276 | 64.231 | 63.797 | 62.752
75.184 |  | G75.184x2.309 | G 2 1/2 | 11 | A | 75.184 | 74.750 | 73.705 | 73.488 | 72.226 |  |  | 72.226 | 72.866 | 73.705 | 73.922 | 75.184 |  |  | 150.368 | 10.5000
75.184 |  | G75.184x2.309 | G 2 1/2 | 11 | B | 75.184 | 74.750 | 73.705 | 73.271 | 72.226
81.534 |  | G81.534x2.309 | G 2 3/4 | 11 | A | 81.534 | 81.100 | 80.055 | 79.838 | 78.576 |  |  | 78.576 | 79.216 | 80.055 | 80.272 | 81.534 |  | 69.8500 | 163.068 | 10.5000
81.534 |  | G81.534x2.309 | G 2 3/4 | 11 | B | 81.534 | 81.100 | 80.055 | 79.621 | 78.576
87.884 |  | G87.884x2.309 | G 3 | 11 | A | 87.884 | 87.450 | 86.405 | 86.188 | 84.926 |  |  | 84.926 | 85.566 | 86.405 | 86.622 | 87.884 |  | 76.2000 | 175.768 | 10.5000
87.884 |  | G87.884x2.309 | G 3 | 11 | B | 87.884 | 87.450 | 86.405 | 85.971 | 84.926
100.330 |  | G100.33x2.309 | G 3 1/2 | 11 | A | 100.330 | 99.896 | 98.851 | 98.634 | 97.372 |  |  | 97.372 | 98.012 | 98.851 | 99.068 | 100.330 |  | 88.9000 | 200.660 | 10.5000
100.330 |  | G100.33x2.309 | G 3 1/2 | 11 | B | 100.330 | 99.896 | 98.851 | 98.417 | 97.372
113.030 |  | G113.03x2.309 | G 4 | 11 | A | 113.030 | 112.596 | 111.551 | 111.334 | 110.072 |  |  | 110.072 | 110.712 | 111.551 | 111.768 | 113.030 |  | 101.6000 | 226.060 | 10.5000
113.030 |  | G113.03x2.309 | G 4 | 11 | B | 113.030 | 112.596 | 111.551 | 111.117 | 110.072
125.730 |  | G125.73x2.309 | G 4 1/2 | 11 | A | 125.730 | 125.296 | 124.251 | 124.034 | 122.772 |  |  | 122.772 | 123.412 | 124.251 | 124.468 | 125.730 |  | 114.3000 | 251.460 | 10.5000
125.730 |  | G125.73x2.309 | G 4 1/2 | 11 | B | 125.730 | 125.296 | 124.251 | 123.817 | 122.772
138.430 |  | G138.43x2.309 | G 5 | 11 | A | 138.430 | 137.996 | 136.951 | 136.734 | 135.472 |  |  | 135.472 | 136.112 | 136.951 | 137.168 | 138.430 |  | 127.0000 | 276.860 | 10.5000
138.430 |  | G138.43x2.309 | G 5 | 11 | B | 138.430 | 137.996 | 136.951 | 136.517 | 135.472
151.130 |  | G151.13x2.309 | G 5 1/2 | 11 | A | 151.130 | 150.696 | 149.651 | 149.434 | 148.172 |  |  | 148.172 | 148.812 | 149.651 | 149.868 | 151.130 |  | 139.7000 | 302.260 | 10.5000
151.130 |  | G151.13x2.309 | G 5 1/2 | 11 | B | 151.130 | 150.696 | 149.651 | 149.217 | 148.172
163.830 |  | G163.83x2.309 | G 6 | 11 | A | 163.830 | 163.396 | 162.351 | 162.134 | 160.872 |  |  | 160.872 | 161.512 | 162.351 | 162.568 | 163.830 |  | 152.4000 | 327.660 | 10.5000
163.830 |  | G163.83x2.309 | G 6 | 11 | B | 163.830 | 163.396 | 162.351 | 161.917 | 160.872

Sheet: BSP Pipe Threads
M Q | BSP Pipe Threads |  | Sort Order - 19 |  | External |  |  |  |  |  |  | Internal
 |  |  |  |  |  | Major Dia |  | Pitch Dia |  | Minor Dia |  |  | Minor Dia |  | Pitch Dia |  | Major Dia |  | Tap Drill | Thread Depth | Thread Runouts
Size | Size Suffix | Thread Designation | Custom Thread Designation | TPI | Class | Max | Min | Max | Min | Max | Min | Class | Min | Max | Min | Max | Min | Max | Basic |  | Basic
1/16 |  | G 1/16-28 | G 1/16-28 | 28 | A | 7.723 | 7.509 | 7.142 | 7.035 | 6.561 |  |  | 6.561 | 6.834 | 7.142 | 7.249 | 7.723 |  | 6.6000 | 15.4460 | 4.5000
1/16 |  | G 1/16-28 | G 1/16-28 | 28 | B | 7.723 | 7.509 | 7.142 | 7.035 | 6.561
1/8 |  | G 1/8-28 | G 1/8-28 | 28 | A | 9.728 | 9.514 | 9.147 | 9.040 | 8.566 |  |  | 8.566 | 8.848 | 9.147 | 9.254 | 9.728 |  | 8.7300 | 19.4560 | 4.5000
1/8 |  | G 1/8-28 | G 1/8-28 | 28 | B | 9.728 | 9.514 | 9.147 | 9.040 | 8.566
1/4 |  | G 1/4-19 | G 1/4-19 | 19 | A | 13.157 | 12.907 | 12.301 | 12.176 | 11.445 |  |  | 11.445 | 11.89 | 12.301 | 12.426 | 13.157 |  | 11.8000 | 26.3140 | 6.5000
1/4 |  | G 1/4-19 | G 1/4-19 | 19 | B | 13.157 | 12.907 | 12.301 | 12.176 | 11.445
3/8 |  | G 3/8-19 | G 3/8-19 | 19 | A | 16.662 | 16.412 | 15.806 | 15.681 | 14.950 |  |  | 14.95 | 15.395 | 15.806 | 15.931 | 16.662 |  | 15.2500 | 33.3240 | 6.5000
3/8 |  | G 3/8-19 | G 3/8-19 | 19 | B | 16.662 | 16.412 | 15.806 | 15.681 | 14.950
1/2 |  | G 1/2-14 | G 1/2-14 | 14 | A | 20.955 | 20.671 | 19.793 | 19.651 | 18.631 |  |  | 18.631 | 19.172 | 19.793 | 19.935 | 20.955 |  | 19.0500 | 41.9100 | 8.5000
1/2 |  | G 1/2-14 | G 1/2-14 | 14 | B | 20.955 | 20.671 | 19.793 | 19.651 | 18.631
5/8 |  | G 5/8-14 | G 5/8-14 | 14 | A | 22.911 | 22.627 | 21.749 | 21.607 | 20.587 |  |  | 20.587 | 21.128 | 21.749 | 21.891 | 22.911 |  | 21.0000 | 45.8220 | 8.5000
5/8 |  | G 5/8-14 | G 5/8-14 | 14 | B | 22.911 | 22.627 | 21.749 | 21.607 | 20.587
3/4 |  | G 3/4-14 | G 3/4-14 | 14 | A | 26.441 | 26.157 | 25.279 | 25.137 | 24.117 |  |  | 24.117 | 24.658 | 25.279 | 25.421 | 26.441 |  | 24.5000 | 52.8820 | 8.5000
3/4 |  | G 3/4-14 | G 3/4-14 | 14 | B | 26.441 | 26.157 | 25.279 | 25.137 | 24.117
7/8 |  | G 7/8-14 | G 7/8-14 | 14 | A | 30.201 | 29.917 | 29.039 | 28.897 | 27.877 |  |  | 27.877 | 28.418 | 29.039 | 29.181 | 30.201 |  | 28.2500 | 60.4020 | 8.5000
7/8 |  | G 7/8-14 | G 7/8-14 | 14 | B | 30.201 | 29.917 | 29.039 | 28.897 | 27.877
1 |  | G 1-11 | G 1-11 | 11 | A | 33.249 | 32.889 | 31.770 | 31.590 | 30.291 |  |  | 30.291 | 30.931 | 31.77 | 31.95 | 33.249 |  | 30.7500 | 66.4980 | 10.0000
1 |  | G 1-11 | G 1-11 | 11 | B | 33.249 | 32.889 | 31.770 | 31.590 | 30.291
1 1/4 |  | G 1 1/4-11 | G 1 1/4-11 | 11 | A | 41.910 | 41.550 | 40.431 | 40.251 | 38.952 |  |  | 38.952 | 39.592 | 40.431 | 40.611 | 41.910 |  | 39.5000 | 83.8200 | 10.0000
1 1/4 |  | G 1 1/4-11 | G 1 1/4-11 | 11 | B | 41.910 | 41.550 | 40.431 | 40.251 | 38.952
1 1/2 |  | G 1 1/2-11 | G 1 1/2-11 | 11 | A | 47.803 | 47.443 | 46.324 | 46.144 | 44.845 |  |  | 44.845 | 45.485 | 46.324 | 46.504 | 47.803 |  | 45.5000 | 95.6060 | 10.0000
1 1/2 |  | G 1 1/2-11 | G 1 1/2-11 | 11 | B | 47.803 | 47.443 | 46.324 | 46.144 | 44.845
1 3/4 |  | G 1 3/4-11 | G 1 3/4-11 | 11 | A | 53.746 | 53.386 | 52.267 | 52.087 | 50.788 |  |  | 50.788 | 51.428 | 52.267 | 52.447 | 53.746 |  | 51.0000 | 107.4920 | 10.0000
1 3/4 |  | G 1 3/4-11 | G 1 3/4-11 | 11 | B | 53.746 | 53.386 | 52.267 | 52.087 | 50.788
2 |  | G 2-11 | G 2-11 | 11 | A | 59.614 | 59.254 | 58.135 | 57.955 | 56.656 |  |  | 56.656 | 57.296 | 58.135 | 58.315 | 59.614 |  | 57.0000 | 119.2280 | 10.0000
2 |  | G 2-11 | G 2-11 | 11 | B | 59.614 | 59.254 | 58.135 | 57.955 | 56.656
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

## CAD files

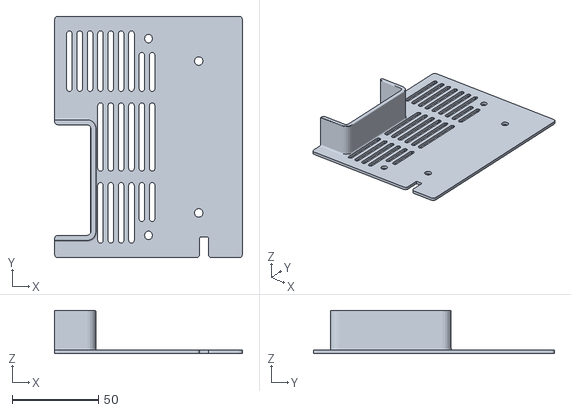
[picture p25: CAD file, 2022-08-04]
Inventor/fechamento2-tipo2.stl
109.0 x 140.0 x 25.0

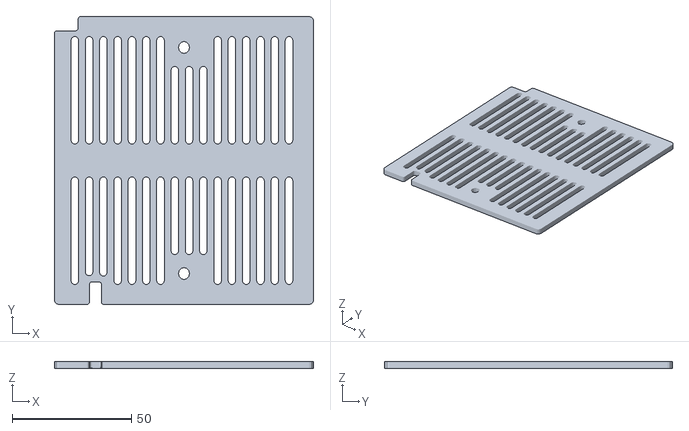
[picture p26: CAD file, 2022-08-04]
Inventor/fechamento3.stl
109.0 x 121.0 x 3.00

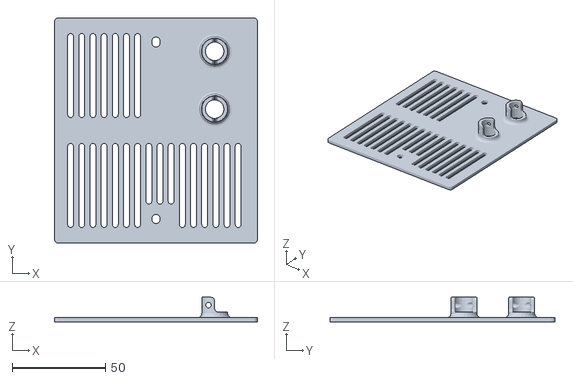
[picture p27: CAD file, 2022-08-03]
Inventor/fechamento1a2.stl
109.0 x 121.0 x 13.2

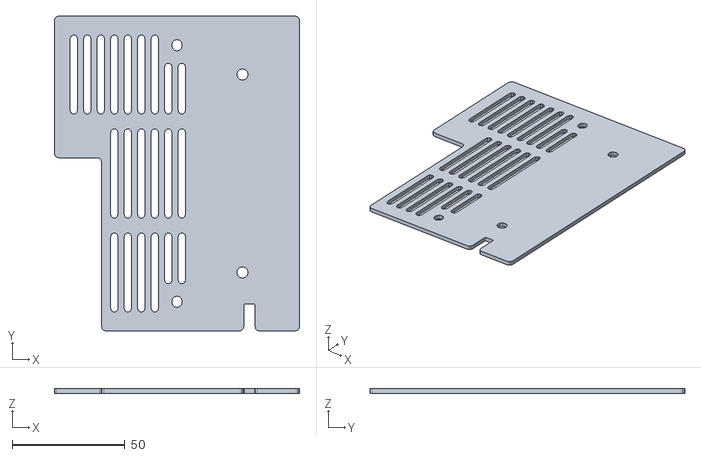
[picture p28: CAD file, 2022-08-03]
Inventor/fechamento2.stl
109.0 x 140.0 x 2.00

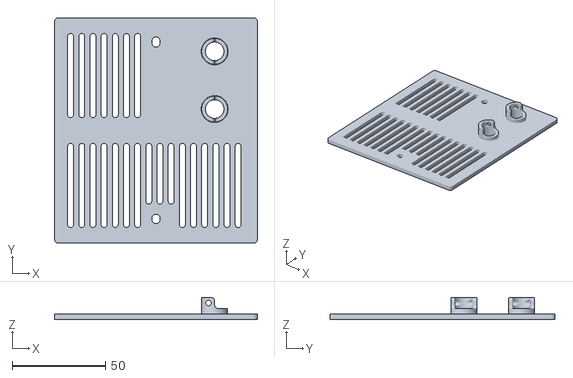
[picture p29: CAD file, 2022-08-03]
Inventor/fechamento1.stl
109.0 x 121.0 x 12.0

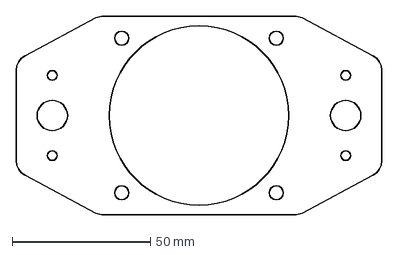
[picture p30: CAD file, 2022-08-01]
Inventor/fechamaneto-baixo.dxf
132.4 x 72.0 mm

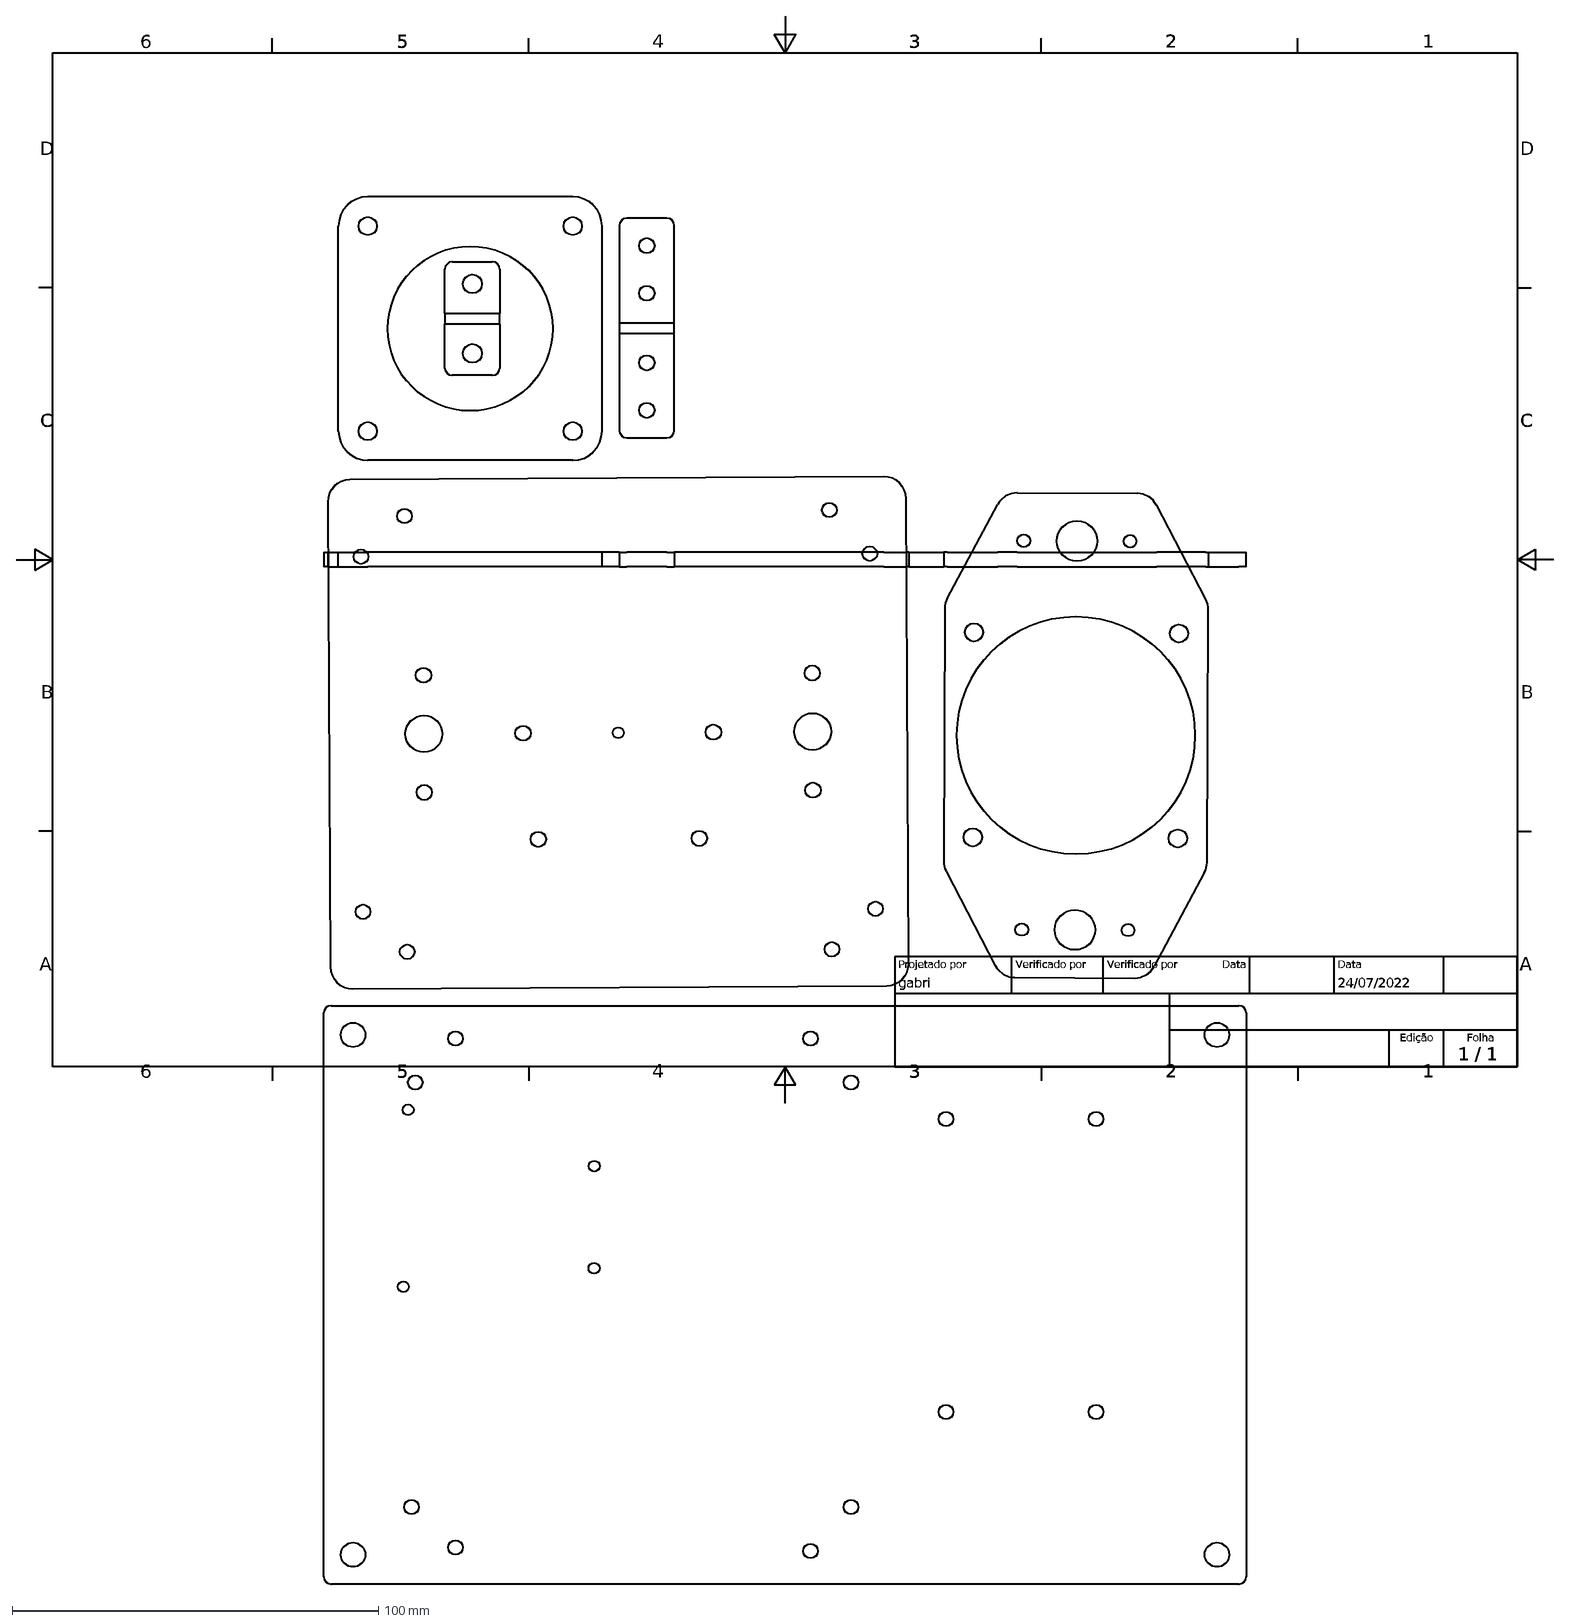
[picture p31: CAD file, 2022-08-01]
Inventor/disposição_chapa-1.dxf
1
2
3
4
5
6
A
B
C
D
gabri
24/07/2022
Projetado por
Verificado por
Data
1 / 1
Edição
Folha

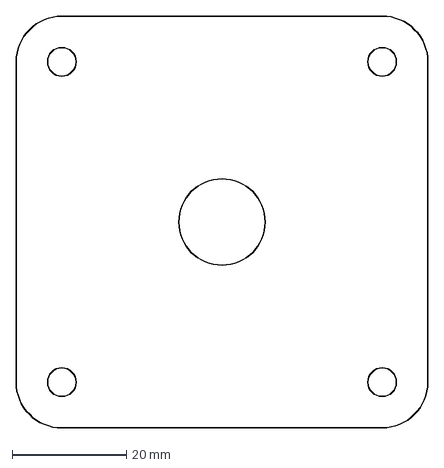
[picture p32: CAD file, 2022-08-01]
Inventor/face_dxf_furo_maior.dxf
72.0 x 72.0 mm

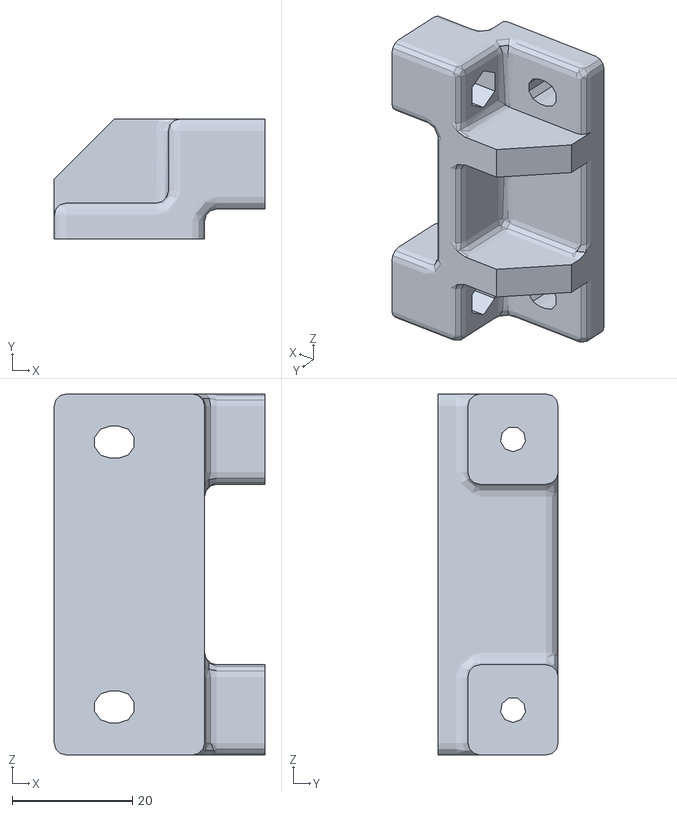
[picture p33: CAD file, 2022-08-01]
Inventor/suporte_termopar_2.stl
35.0 x 20.0 x 60.0

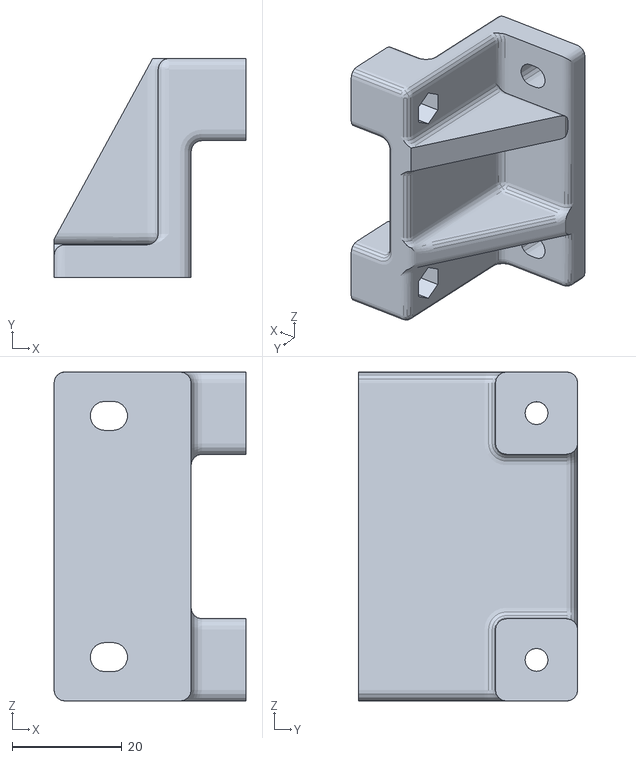
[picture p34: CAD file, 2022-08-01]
Inventor/suporte_termopar.stl
35.0 x 40.0 x 60.0

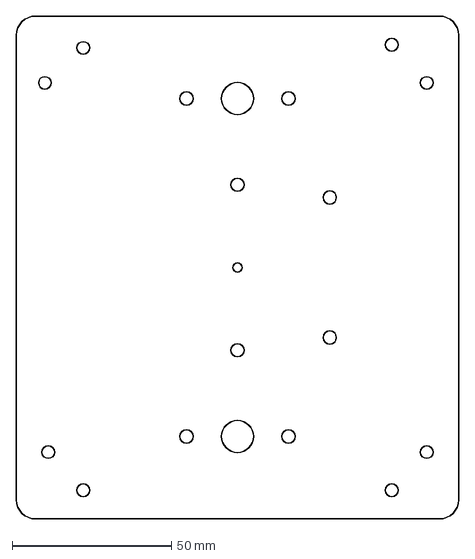
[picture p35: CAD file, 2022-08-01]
Inventor/face_cima.dxf
139.0 x 158.0 mm

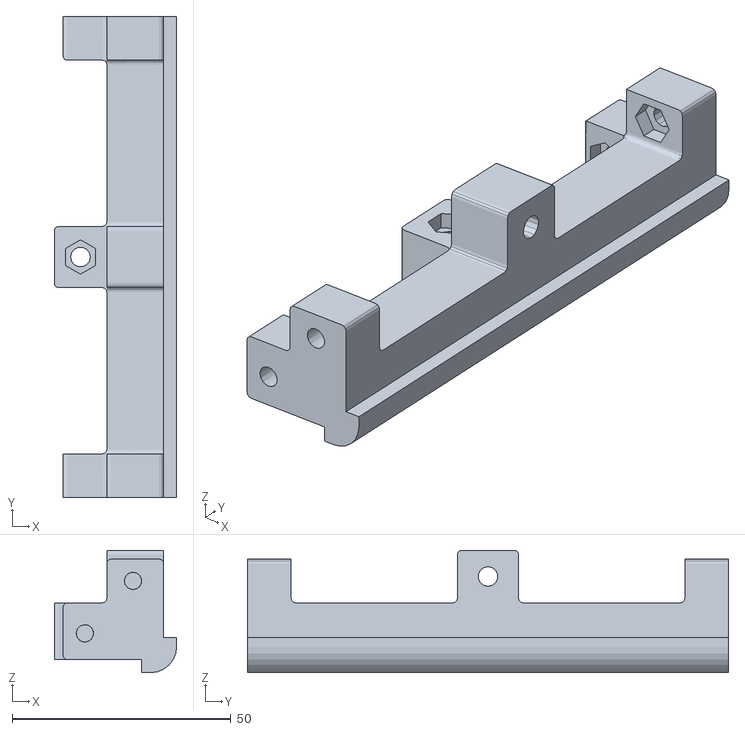
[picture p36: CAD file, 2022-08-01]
Inventor/suporte_fechamento.stl
28.0 x 110.0 x 28.0

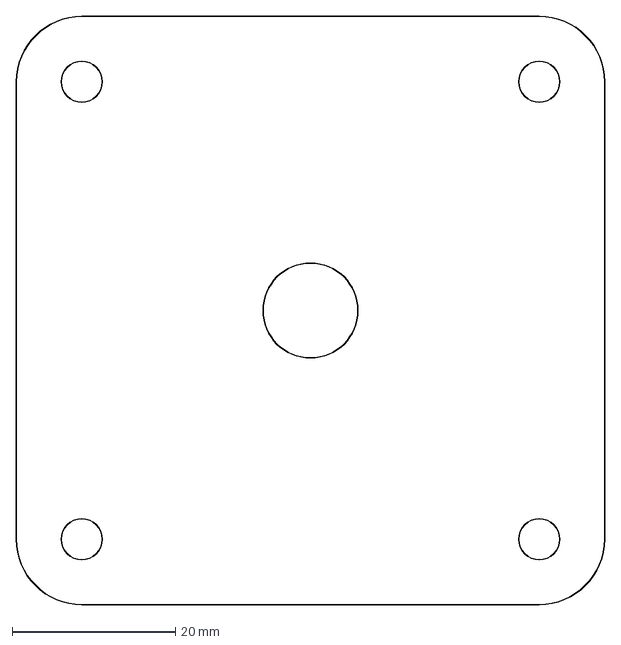
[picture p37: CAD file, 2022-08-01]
Inventor/face_dxf_corte_menor.dxf
72.0 x 72.0 mm

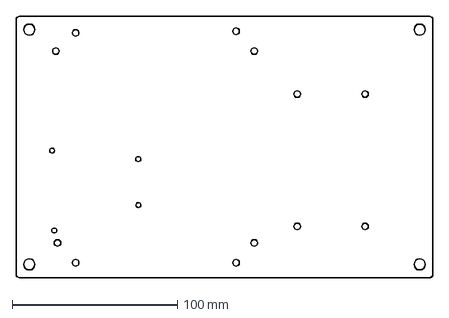
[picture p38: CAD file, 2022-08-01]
Inventor/face_baixo_suporte.dxf
252.0 x 158.0 mm

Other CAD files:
Inventor/fechamento1a.stl
Inventor/suporte-fonte.stl
Inventor/suporte-fonte_energia.stl
Inventor/tampa-baixo.dxf
Inventor/Base.ipt
Inventor/Base_isolante.ipt
Inventor/Calorímetro.iam
Inventor/Calorímetro_montagem.ipt
Inventor/Corpo_1.ipt
Inventor/Corpo_2.ipt
Inventor/Design Data/AIT/Mold Design/mold design stop pin.ipt
Inventor/Design Data/Cable & Harness/pt-BR/harness.iam
Inventor/Design Data/Tube & Pipe/pt-BR/piping runs.iam
Inventor/Fonte/ATX Power Supply v1.iam
Inventor/Fonte/Blades.ipt
Inventor/Fonte/Body (1).ipt
Inventor/Fonte/Body.ipt
Inventor/Fonte/Box.ipt
Inventor/Fonte/Button.ipt
Inventor/Fonte/Casq.ipt
Inventor/Fonte/Cover.ipt
Inventor/Fonte/Fonte ATX.iam
Inventor/Fonte/Grelha Prot Vent 120.ipt
Inventor/Fonte/IEC Plug.iam
Inventor/Fonte/On-Off Switch.iam
Inventor/Fonte/Peça28.ipt
Inventor/Fonte/Ventax 119x119x26 (1).iam
Inventor/Fonte/ground.ipt
Inventor/Fonte/pin1 (1).ipt
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

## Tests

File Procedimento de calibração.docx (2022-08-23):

Procedimento de calibração

Regular a tensão para o valor desejado (opcional).

Colocar a temperatura para a qual a calibração será feita e clicar em calibrar. Os três últimos valores que aparecem são os parâmetros PID para o calorímetro calibrado.

Nos ensaios foram usados como parâmetro P a média dos parâmetros e como I e D os maiores valores encontrados no teste.

Estes valores devem ser inseridos na janela do teste para a realização do mesmo.

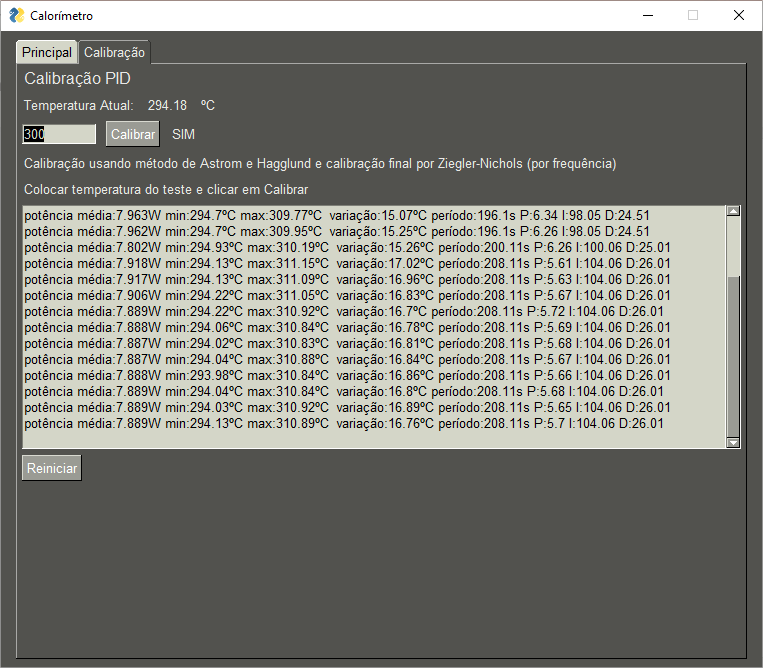
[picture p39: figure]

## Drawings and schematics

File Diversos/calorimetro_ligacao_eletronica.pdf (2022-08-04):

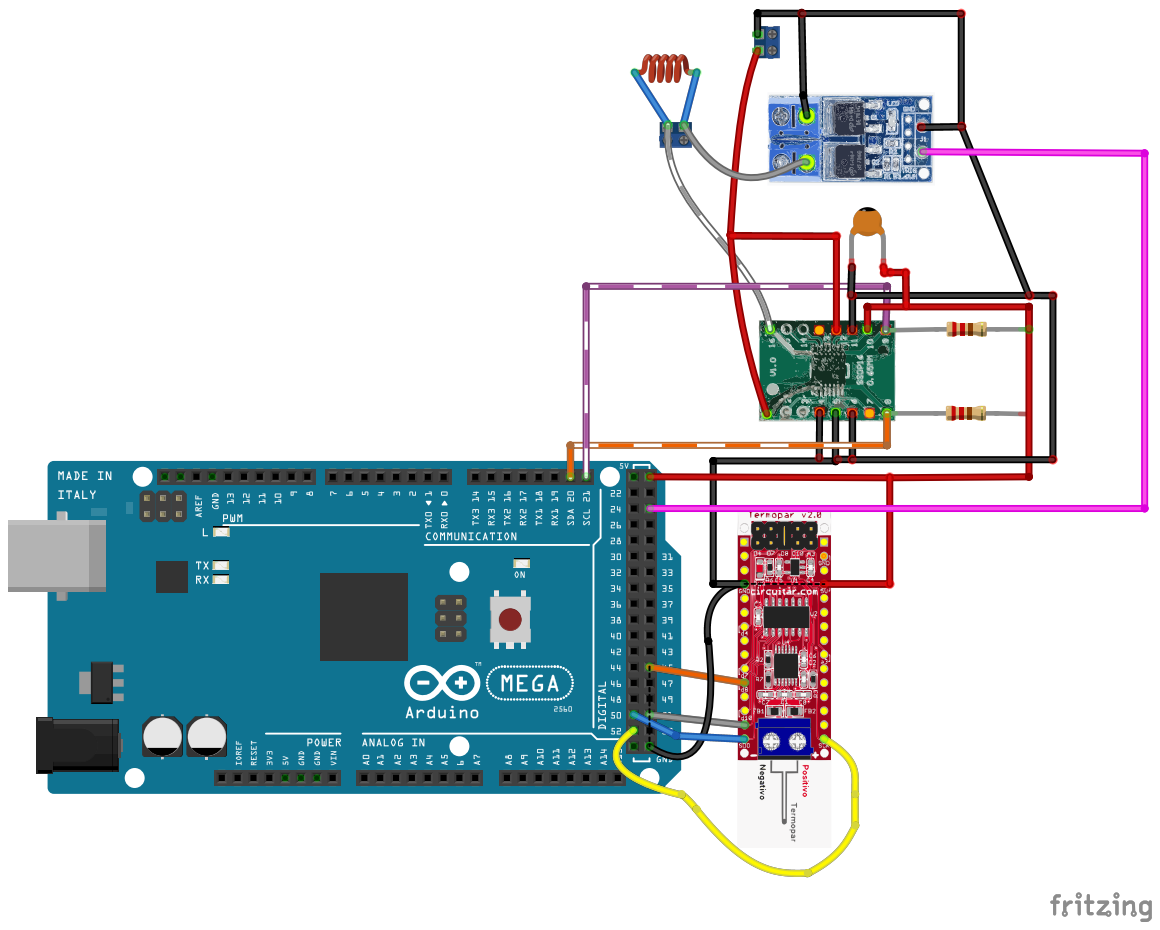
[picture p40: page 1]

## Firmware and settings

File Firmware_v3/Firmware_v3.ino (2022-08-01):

#include "Arduino.h"
#include <INA.h>                  // Biblioteca Zanshin INA https://github.com/Zanduino/INA/wiki
#include "Nanoshield_Termopar.h"  //Biblioteca termopar https://github.com/circuitar/Nanoshield_Termopar
#include <Wire.h>
#include "max6675.h"        //https://github.com/adafruit/MAX6675-library
#include <EEPROM.h>


/* Variávris para sensor de corrente e impressão*/
const uint32_t SHUNT_MICRO_OHM{2000};  // Resistencia shunt resistance em  MicroOhm. 100000 é 0.1 Ohm
const uint16_t MAXIMO_AMPERE{15};          // Maximo valor de corrente do sensor
uint8_t        devicesFound{0};          
INA_Class      INA;                      
unsigned long leituras=0;
unsigned long tempo_atual = micros();;   //tempo em microsegundos desde que o programa comecou - dá overflow em 70 minutos
unsigned long tempo_anterior = micros();;
float leitura_tensao, leitura_corrente, tempo_conversao;
double integrador_energia=0.0;

bool SAIDA_MANUAL = false;
bool ASTROM = false;
int saida_manual_valor = 0;

/*para o segundo termopar - ele consome pouca corrente 1.6mA, o pino do arduino consegue alimentar*/
int gnd_termopar = 22;
int alimentacao_termopar = 24;
int termopar_sck_pin = 26;
int termopar_cs_pin  = 28;
int termopar_so_pin  = 30;

static char buffKP[10], buffKI[10], buffKD[10]; 
float k;
  
MAX6675 termopar(termopar_sck_pin, termopar_cs_pin, termopar_so_pin);

  int LEITURAS_POR_CICLO=125;
  //double Output;
  double lastErr;
  double errSum=0;
  unsigned long lastTime;
  double divisor=10;
  double minOut=0;
  double maxOut=LEITURAS_POR_CICLO;
  //double Setpoint;


   int endereco_kp_eeprom=0;
   int endereco_ki_eeprom=3;
   int endereco_kd_eeprom=6;

//FIM PID MANUAL





/*Variáveis de entrada do algoritmo PID. KP é o proporcional. KI o integrativo e Kd o derivativo. Alterar esses valores pode melhorar o ajuste da curva de aquecimento*/
#define KP  19.48//39.75
#define KI  54
#define KD  10.5

/*esse valor estabilizou, mas oscila muito depois a energia
#define KP  59.6
#define KI  7.91
#define KD  5.81

/* variou - diminuir kp (ficou pior com 0.5)
#define KP  1.087
#define KI  32
#define KD  8
/*
#define KP  0.1
#define KI  0
#define KD  0.0
/*
#define KP  0.15
#define KI  87
#define KD  21.75

/*oscilou +-15graus
#define KP  0.15
#define KI  43
#define KD  0.0


/* remember - calibrado pelo pid do site, com varios valores, mas ficou variano ao redor de 10 graus, mas nao ficou ruim. Nao fica ligando 100% e depois zero*/
/* Fica variando mas permitir leituras #define KP  0.132
#define KI  49.87
#define KD  6.71

/*
//pelo metodo do ziegler - ruim, demora mto
#define KP  0.024
#define KI  128
#define KD  32

/*
//pelo metodo de cohen-coon
#define KP  8.413
#define KI  153.34
#define KD  23.24

/*
//calibrado pelo metodo do paper(skogestad), usando valores de delta y inf. Caiu 12 graus e 
#define KP  0.0297
#define KI  99.2
#define KD  0


*/

/* Variáveis para termopar e PID*/
#define PINO_SAIDA 25       //Saída da carga
double Setpoint=-10, Input=0, Output=0, saida_pwm_manual=0;  

double Kp = KP, Ki = KI, Kd = KD;




Nanoshield_Termopar tc(45, TC_TYPE_K, TC_AVG_OFF);
float temperatura_atual=0, temperatura_atual2=0;
float temperatura_ambiente;

int tempo_ligado=0,tempo_exibir_dados=1000;
long temp=5;
unsigned long tempo_atual_pwm = millis(); 
unsigned long tempo_anterior_pwm = millis();
unsigned long  tempo_atual_leitura=0, tempo_anterior_leitura=0; 
int INTERVALO_PWM_MANUAL = 1990;  //tempo que chama o pwm em milisegundos
boolean LIGADO=false;

int INTERVALO_leitura = 1990;  //milissegundos - estava 1990

//variáveis para medias
float MEDIA_tempo_conversao=0, MEDIA_temperatura=0,  MEDIA_corrente=0, MEDIA_tensao=0;   
int contagem_para_media=0;
int astrom_valor=0;
int limite_saida = LEITURAS_POR_CICLO;
int contar_PID_ate_LEITURAS_POR_CICLO=0; 

void setup() {
  Serial.begin(115200);
  pinMode(PINO_SAIDA, OUTPUT);
  
  /* Inicia o sensor de corrente*/
  devicesFound = INA.begin(MAXIMO_AMPERE, SHUNT_MICRO_OHM, INA260);  
  while (devicesFound == 0) {
    Serial.println(F("Não encontrou sensor de corrente, testando novamente em 10 segundos..."));
    delay(10000);                                             
    devicesFound = INA.begin(MAXIMO_AMPERE, SHUNT_MICRO_OHM, INA260);  
  } 
  
  /* Configurações do sensor de corrente*/                                                          
  INA.setBusConversion(8500);             // Tempo máximo de conversão de 8.244ms
  INA.setShuntConversion(8500);           // Tempo máximo de conversão de 8.244ms
  INA.setAveraging(1);                  // Média de leituras antes de dar resultado. Com 4 aproximadamente 66ms cada leitura 
  INA.setMode(INA_MODE_CONTINUOUS_BOTH);  // Bus/shunt medido continuamente

//termopar 2 alimentação
  pinMode(alimentacao_termopar, OUTPUT); 
  pinMode(gnd_termopar, OUTPUT); 
  digitalWrite(alimentacao_termopar, HIGH);
  digitalWrite(gnd_termopar, LOW);



  /* Inicia Termopar e PID */
  tc.begin();
  tc.read();
  Setpoint = temp;
              

  /*Imprime configuracoes atuais PID no software*/
              Serial.print("P:");
               dtostrf(Kp, 7, 2, buffKP);
               Serial.print(buffKP);
               dtostrf(Ki, 7, 2, buffKI);
               Serial.print("I:");
               Serial.print(buffKI);
               dtostrf(Kd, 7, 2, buffKD);
               Serial.print("D:");
               Serial.print(buffKD); 
               Serial.print("\n");




  
}  // fim setup()

void Imprime_erro_termopar() { 
  if (tc.isOpen()) {Serial.print("(Circuito aberto) \n");  } 
  else if (tc.isOverUnderVoltage()) {Serial.print("(Sub/supertensao) \n"); } 
  else if (tc.isInternalOutOfRange()) {Serial.print("(Temperatura interna fora de valor) \n");  } 
  else if (tc.isExternalOutOfRange()) {Serial.print("(Temperatura externa fora de valor) \n"); }
  }





void loop() {
 tempo_atual_leitura = millis();


 
/* Função chamada sempre que leitura termina. Le os sensores e é a saida do PWM para que seja no periodo da leitura*/
if (INA.conversionFinished(0)){
    contagem_para_media++;
    
    leitura_tensao = (float)INA.getBusMilliVolts(0)/1000;
    if (INA.getBusMicroAmps(0) >=0){
        leitura_corrente = (float)INA.getBusMicroAmps(0)/1000;   }
    else{ leitura_corrente = 0.0; }
    
    MEDIA_corrente = MEDIA_corrente + leitura_corrente;
    MEDIA_tensao = MEDIA_tensao + leitura_tensao;
    
    tempo_atual_pwm = millis();
    tempo_atual=micros();
    tempo_conversao = (float)(tempo_atual-tempo_anterior)/1000;
    MEDIA_tempo_conversao = tempo_conversao + MEDIA_tempo_conversao ;
    
    /* acontece quando deu overflow do micros() - somente perde a leitura do overflow */
    if(tempo_anterior>tempo_atual){ tempo_conversao = (float)(tempo_atual)/1000;  }
     tempo_anterior = tempo_atual;


       /* Calcula a energia no período */
    integrador_energia = integrador_energia + (leitura_tensao*leitura_corrente*tempo_conversao)/1000;


    /* Controle da saída PWM manual, dentro do loop da leitura */
    
    
    
    //if ((tempo_atual_pwm <tempo_anterior_pwm+tempo_ligado) && LIGADO==true){ digitalWrite(PINO_SAIDA, HIGH);      }
    //    else {digitalWrite(PINO_SAIDA, LOW);  }

    if (float(contar_PID_ate_LEITURAS_POR_CICLO) < saida_pwm_manual && LIGADO==true ){  digitalWrite(PINO_SAIDA, HIGH);   }
    else {digitalWrite(PINO_SAIDA, LOW);  }
/*Imprime para o usuario os valores e zera o integrador de energia*/
    if (contar_PID_ate_LEITURAS_POR_CICLO>LEITURAS_POR_CICLO-1) {  
        
        /* leitura do termopar*/
        tc.read(); //le o termopar
        if (tc.hasError()) { Imprime_erro_termopar();  } 
      
       // temperatura_atual2 = termopar.readCelsius();
        temperatura_atual = tc.getExternal();
        temperatura_ambiente=tc.getInternal();

        
    
        MEDIA_tempo_conversao = MEDIA_tempo_conversao; 
        MEDIA_corrente = MEDIA_corrente/contagem_para_media;    
        MEDIA_tensao = MEDIA_tensao/contagem_para_media;    
    
        static char buff[250], bufftensao[12], buffcorrente[12], bufftempo[11], bufftemperatura[10],bufftemp2[10], buffpwm[10], buffleituras[10], buffenergia[50];
        dtostrf(MEDIA_corrente, 9, 4, buffcorrente);
        dtostrf(MEDIA_tempo_conversao, 10, 3,  bufftempo);
        dtostrf(MEDIA_tensao, 8, 3, bufftensao);
        dtostrf(temperatura_atual, 8, 2, bufftemperatura);
        dtostrf(saida_pwm_manual, 8, 2, buffpwm);
        dtostrf(leituras, 8, 0, buffleituras);
        dtostrf(integrador_energia, 9, 2, buffenergia);
        //dtostrf(temperatura_atual2, 9, 2, bufftemp2);
        dtostrf(temperatura_ambiente, 9, 2, bufftemp2);
    
        sprintf(buff, "L%s Tensao V:%s,Corrente mA:%s, tempo de conversao:%s, saída pwm:%s, leitura:%s, integracao energia: %s, temperatura 2: %s\n", bufftemperatura, bufftensao, buffcorrente, bufftempo, buffpwm, buffleituras, buffenergia, bufftemp2) ; //falta colocar output
        Serial.print(buff);
    
        leituras++;

        integrador_energia=0;
        contagem_para_media=0;
        MEDIA_tempo_conversao = 0; 
        MEDIA_temperatura = 0; 
        MEDIA_corrente = 0;    
        MEDIA_tensao = 0;
        
    
        /***********COMECO DO CALCULO PID*************************************************************/

        // Calcula a diferença de tempo para o diferencial
        unsigned long now = millis();
        double timeChange = (double)(now - lastTime);
        timeChange=timeChange/1000;  //converte para segundos
        // Calculata erro, P, I e D 
        double error = Setpoint - temperatura_atual;
        errSum += error * timeChange;
        double dErr = (error - lastErr) / timeChange;

        // Calcula a saida pelo artigo Vance
        double newOutput = Kp*(error + (1/Ki)*errSum + Kd*dErr);
        Serial.print("Saida PID:"); Serial.print(newOutput); Serial.print("\n");
        //Serial.print( "temp ambiente");
        //Serial.print(tc.getInternal());
        //Serial.print( "\n");
        
        // Modula valores de saida
        if (newOutput>LEITURAS_POR_CICLO) { Output = LEITURAS_POR_CICLO;  
        //ZERAR O INTEGRATIVO PARA NÃO TER PICO GIGANTE
        errSum =0;
        } 
        else if (newOutput<0) { Output = 0;  } 
        else {  Output = newOutput;   }

        // Atualiza variaveis
        lastErr = error;
        lastTime = now;

      /**********************FIM DO CÁLCULO DO PID*************************************************************/
      //FIM DO PID -- OUTPUT é a saída

        if (SAIDA_MANUAL == true){
           saida_pwm_manual = saida_manual_valor;
        }
        else if (ASTROM== true){
          if (temperatura_atual<astrom_valor){ saida_pwm_manual = LEITURAS_POR_CICLO; }
          else{ saida_pwm_manual=0;     }        
        }      
        else { 
          if (Output>limite_saida){ saida_pwm_manual = limite_saida;      }
          else{ saida_pwm_manual = Output; }
         }

         if (saida_pwm_manual>limite_saida){saida_pwm_manual=limite_saida; }
        contar_PID_ate_LEITURAS_POR_CICLO=0;
        //tempo_anterior_pwm = tempo_atual_pwm;
        //tempo_ligado = (saida_pwm_manual*INTERVALO_PWM_MANUAL)/255;
        
     }
   contar_PID_ate_LEITURAS_POR_CICLO++;
} //FICOU AQUI


/* Recebe os comandos do software*/
if (Serial.available() > 0) {
       
    char leitura = Serial.read(); // Variavel que receberá os valores enviados pelo programa em python
    temp = Serial.parseInt();
    
    
    switch (leitura) {
          
            case 'T':
            Serial.print("SETAR TEMPERATURA ");
            Setpoint=temp;
            Serial.print(temp);
            Serial.print("\n");
            errSum=0;
            if(temp<2){LIGADO = false;}
            else {LIGADO = true;}
            break;   

            case 'L':
            Serial.print("TEMPO PARA EXIBIR DADOS ");
            tempo_exibir_dados=temp;
            Serial.print(temp);
            Serial.print("\n");
            break;

          //se receber M muda saida para manual

           case 'M':
            Serial.print("ARDUINO: SAIDA MANUAL");
            SAIDA_MANUAL = true;
            LIGADO = true;
            saida_manual_valor = temp;
            Serial.print(saida_manual_valor);
            Serial.print("\n");
            break;

            case 'Z':
            
            if (ASTROM){
              LIGADO = false;
              ASTROM = false;
              saida_pwm_manual=0;
              Serial.print("ARDUINO: ASTROM DESLIGADO");
              }
            else{
            LIGADO = true;
            ASTROM = true;
            astrom_valor=temp;
            Serial.print("ARDUINO: ASTROM LIGADO");
            //Serial.print(astrom_valor);
            }
          
            break;


            //LIMITE DE SAIDA
            case 'Y':
            limite_saida=temp;
            Serial.print("O Limite de Saida:");
            Serial.print(limite_saida);
            Serial.print("\n");
            break;
            
            case 'S':
            Serial.print("KP LIDO EEPROM");
            //EEPROM.put(endereco_kp_eeprom, highByte(float(Kp)));  
            //EEPROM.put(endereco_kp_eeprom+1, lowByte(float(Kp))); 
           
            Serial.print("KP LIDO EEPROM");
            //Serial.print(word(EEPROM.read(endereco_kp_eeprom), EEPROM.read(endereco_kp_eeprom +1)));  
                  
            break;

          //Se receber A muda saida para automatica do PID
          case 'A':
            Serial.print("ARDUINO: SAIDA AUTOMATICA PID\n");
            SAIDA_MANUAL = false;
            LIGADO = false;
            
            break;


            case 'P':
            //Serial.print(temp);
               Kp = float(temp/1000.0);
               //Serial.print(myPID.GetKp());
              //COMENTEI myPID.SetTunings(Kp, Ki, Kd); 
               //Serial.print(myPID.GetKp()); 
                 
            break;
            
            
            case 'I':
             Ki = float(temp/1000.0);
             if (Ki==0){Ki=0.01;} //evitar divisao por 0
               //Serial.print(myPID.GetKi());
              //COMENTEI myPID.SetTunings(Kp, Ki, Kd); 
               //Serial.print(myPID.GetKi());           
            break;


            case 'D':
             Kd = float(temp/1000.0);
               //Serial.print(myPID.GetKd());
             //COMENTEI  myPID.SetTunings(Kp, Ki, Kd); 

               
               
               
              
               Serial.print("P:");
             //  k = myPID.GetKp();
               k=Kp;
               dtostrf(k, 7, 2, buffKP);
               Serial.print(buffKP);
              // k=myPID.GetKi();
              k=Ki;
               dtostrf(k, 7, 2, buffKI);
               Serial.print("I:");
               Serial.print(buffKI);
               //k=myPID.GetKd();
               k=Kd;
               dtostrf(k, 7, 2, buffKD);
               Serial.print("D:");
               Serial.print(buffKD); 
               Serial.print("\n");

                      
            break;
            
                  
          }
    }




}  //fim do loop

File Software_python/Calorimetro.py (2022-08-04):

#Instalar bibliotecas pysimpleGUI, pyserial, numpy


from grafico import *	#importa o arquivo com dados da tela
from portaserial import *

import time
#import matplotlib.pyplot as plt    #pip install matplotlib==3.0.0 --user
#import pyqtgraph as pg #biblioteca pyqtgraph para os graficos
#from PyQt5 import QtWidgets, QtCore

#colado

#from pyqtgraph import PlotWidget, plot
#import sys  # We need sys so that we can pass argv to QApplication
#import os
#from random import randint
#import os
#import shutil


nome = ""
portaserial = ""
temperatura = 0
porta_aberta = 0
captura = 0
tempo_total_milisegundos = 0.0
saida_manual=False

#para plotar os graficos
#plt.ion() #habilita modo interativo matplotlib
valores_temperatura=list()
valores_tempo=list()
grafico_temperatura=False
colocou_amostra = False
colocou_amostra_texto = "não"
leitura_recebida = 0
Kp=0
Ki=0
Kd=0
atingiu_setpoint_primeira_vez=0
#soma_para_media_energia=0
#soma_para_media_tempo=0
finalizou_período_negativo=0
temperatura_atual=0
Energia_colocada=0
Tempo_conversao=0
#esta_ligado=False
valores_para_analise=[]
tempo_para_analise=[]
contador_variacao_erro=0
medias_potencias=[]
medias_maximo=[]
medias_minimo=[]
medias_periodo=[]
medias_temperatura=[]
texto_usuario=""
texto_usuario=[]
indices=[]


medias_minimo_depois=[]
medias_maximo_depois=[]
medias_periodo_depois=[]
medias_potencias_depois=[]
texto_usuario_depois=[]
ocorreu_teste=False
z=[0,0,0]
zant=[0,0,0]
astrom=False
Limite_saida=False
MAXIMO_SAIDA_PWM=125
#temp_funcao=[]
from analise import *


while True:
				

	#print (nome)
	event, values = janela.Read(timeout=10)
	
	if event == 'Buscar porta' :
		portas = busca_serial()
		print('Portas disponíveis:')
		print(portas)
		janela['selecao'].update(values=portas)
		

	if event == 'selecao' :		#alguma porta serial é selecionada
		portaserial = values['selecao']
		print(portaserial)
		janela['portaserial'].update(portaserial) 
	
	if event == 'Conectar':
		if (porta_aberta==0):  #não aberta
			serialArduino = inicia_serial(portaserial)
			if (serialArduino != "Erro"):
				janela['status'].update('conectado')
				porta_aberta=1

	if event == 'Desconectar':
		try:
			fecha_serial(serialArduino)
			janela['status'].update('desconectado')
			porta_aberta=0
		except:
			print("sem porta aberta")
	
	if event == 'Selecionar':
		temperatura = values['temperatura']
		if temperatura != "":
			tempstring = temperatura + " ºC"
			janela['mostratemperatura'].update(tempstring)
		else: print("Insira a temperatura do teste")

	if event == sg.WIN_CLOSED:  #se fechar a tela interrompe o algoritmo
		texto_str = 'T0\n'
		if (serialArduino.isOpen()):
			serialArduino.write(str.encode(texto_str))
			time.sleep(1)
			serialArduino.write(str.encode(texto_str))
			time.sleep(1)
			fecha_serial(serialArduino) 
			 
		break

	if event == 'Aquecer':

		if porta_aberta == 0:
			print("Verifique conexão")
			janela['ligar'].update('DESLIGADO. Verifique conexão serial')
		elif temperatura==0:
			print("Selecione a temperatura")
			janela['ligar'].update('DESLIGADO. Selecione temperatura')
		elif (float(tensao_atual)<1.0 and int(temperatura)!=0 ):
			print ("Ligue a fonte")
			janela['ligar'].update('DESLIGADO. Ligue a fonte')
		elif (porta_aberta != 0 and int(temperatura)!=0):
			print('Aquecimento ligado para %s graus' %temperatura)
			texto_str = 'T' + str(temperatura) + '\n'
			print(texto_str)
			serialArduino.write(str.encode(texto_str))
			janela['ligar'].update('LIGADO')
			esta_ligado=True

		

		else: print("Verificar a conexão serial")	
    	
	

	if event == 'Desligar':
		if (porta_aberta != 0):
			print('Aquecimento desligado')
			texto_str = 'T0\n'
			print(texto_str)
			serialArduino.write(str.encode(texto_str))
			janela['ligar'].update('DESLIGADO                  ')
			esta_ligado=False

		else: print("verificar conexão")

	if event == 'Definir':
		if (porta_aberta != 0):
			saida_manual_valor = values['saida_manual']
			try: 
				saida_manual_valor_float = float(saida_manual_valor)
				if saida_manual_valor_float >= 0 and saida_manual_valor_float <= 1:
					janela['valor_saida_manual2'].update(saida_manual_valor_float)
					saida_manual_valor_float2 = saida_manual_valor_float

					
				else: print("fora valor")	
			except:
				print("Erro valor")

	if event == 'Ligar Manual':
		if (porta_aberta != 0):
			try:
				saida_string_manual = 'M'+ str(int(saida_manual_valor_float2*MAXIMO_SAIDA_PWM)) +'\n'   #SAIDA DE 0 A MAXIMO_SAIDA_PWM
				serialArduino.write(str.encode(saida_string_manual))
				saida_manual=True
				print("Saida Manual")
				print (saida_manual_valor)
				texto_para_saida = 'Saída: MANUAL:' + str(saida_manual_valor_float)
				janela['saida_status'].update(texto_para_saida)
				#janela['valor_saida_manual'].update(saida_manual_valor_float)
			except:
				print("selecione valor")


	if event == 'Calibrar':
		if (astrom and porta_aberta != 0):
			astrom = False;
			janela['astrom'].update('NÃO')
			serialArduino.write(str.encode("Z"))
			esta_ligado=False
		elif(porta_aberta != 0):
			astrom = True;
			janela['astrom'].update('SIM')
			astrom_temperatura = values['astrom_valor']
			astrom_string = 'Z'+ str(astrom_temperatura) +'\n'   
			serialArduino.write(str.encode(astrom_string))
			esta_ligado=True

			

	if event == 'Limite Saida':
		if (Limite_saida and porta_aberta != 0):
			Limite_saida = False;
			janela['limite_saida_texto'].update('NÃO')
			serialArduino.write(str.encode("Y125"))
			
		elif(porta_aberta != 0):
			limite_saida_valor = values['limite_saida']


			Limite_saida = True;
			limite_saida_numerico = int(float(limite_saida_valor)*MAXIMO_SAIDA_PWM)
			if (limite_saida_numerico>=0 and limite_saida_numerico<=MAXIMO_SAIDA_PWM):
				string_saida_limite = "SIM "+ str(limite_saida_valor)
				janela['limite_saida_texto'].update(string_saida_limite)	
				print(limite_saida_numerico)
				serialArduino.write(str.encode('Y'+ str(limite_saida_numerico) +'\n'))
			else:
				janela['limite_saida_texto'].update('Valor inválido')
			



	if event == 'COLOCOU AMOSTRA':
		ja_colocou_amostra = colocou_amostra()
		if ja_colocou_amostra== True: 
			janela['ja_colocou_amostra'].update('SIM')
		else:
			janela['ja_colocou_amostra'].update('NÃO')
			

	if event == 'Desligar Manual':
		if (porta_aberta != 0):
			janela['saida_status'].update('Saída: AUTOMÁTICA')
			serialArduino.write(str.encode("A"))
			saida_manual=False
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
